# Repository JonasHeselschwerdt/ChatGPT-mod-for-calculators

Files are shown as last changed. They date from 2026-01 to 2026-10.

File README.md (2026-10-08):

# About this project

This repository features a hardware design and code for an ESP32S3 Wroom. With the provided ressources it is possible, to turn any ordinary, non-programmable school calculator into a powerful and programmable device, that connects to the internet via Wifi.
One possible usecase for such a device is the communication with LLM's like ChatGPT, which is implemented in the code.
There are two versions of hardware available. The second, newer version allows for an installation in any calculator with small changes (to the UI-Board and some 3D-prints). The first version is designed specifically to be compatible with the Casio FX87 or FX991.

This is an independent modification, I am not affiliated with Casio Computer Co.,Ltd. or Casio Europe GmbH in any way.

## Documentation of V2

Linked Image (https://youtu.be/zLtktpHgP-4)

## Documentation of V1

Linked Image (https://youtu.be/Xx7Nprghpbg)

## Contact:

If you find bugs in the firmware or you need help setting the device up you can contact me on Youtube, Instagram or here on Github.
Of course I am open to suggestions and collaborations!

Youtube: @ElectrJonics

Instagram: @electrjonics

© 2026 Jonas Heselschwerdt

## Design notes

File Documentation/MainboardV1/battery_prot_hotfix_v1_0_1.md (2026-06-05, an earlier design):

# Hotfix documentation:

I just found out that there is a small flaw in the hardware design of the device.
The battery I recommend for the device (JBL Clip 2 replacement battery) has a battery protection already implemented (see picture below). This can lead to the following problem: When the battery cell voltage drops below a certain treshold of 2.5V the internal battery protection disconnects the output terminal with a mosfet. The battery protection on the PCB misinterprets this as a deeply depleted battery and therefore refuses to charge the battery. In this situation the 2 battery protections deadlock each other. 

To fix this, make the following changes to the PCB:

1) Disconnect JP1
2) Connect the positive battery terminal (red) to Pin 1 of JP1
3) Connect the negative battery terminal (black) directly to GND on one of the pads

With these changes the battery protection on the PCB gets bypassed, as it is not necessary and can cause the problem mentioned above.

Before you attempt this workaround make sure that your battery has a battery protection integrated (experimental or through a datasheet)! Do not operate a battery without any battery protection!

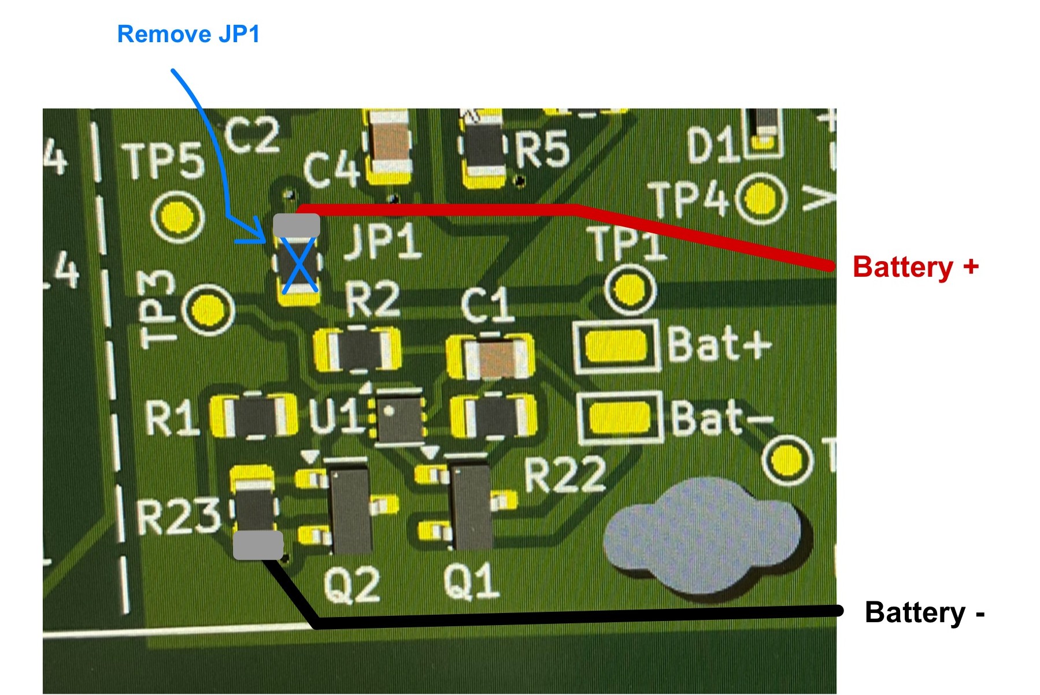
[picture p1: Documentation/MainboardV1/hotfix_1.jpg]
Workaround overview


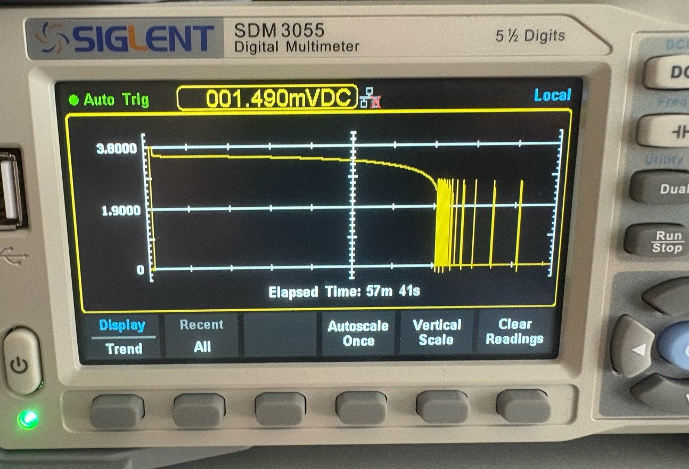
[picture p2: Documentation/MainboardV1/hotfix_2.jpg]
Internal UVP validated


The UVP integrated into the battery shuts off at ~2.5V. Test performed with discharge current of 600mA.
The cell voltage recovers when the load is disconnected, when the load gets reconnected
the cell voltage drops down again, this is why the output voltage 'oscillates' slowly at first. This
eventually stops as the cell voltage goes down further.

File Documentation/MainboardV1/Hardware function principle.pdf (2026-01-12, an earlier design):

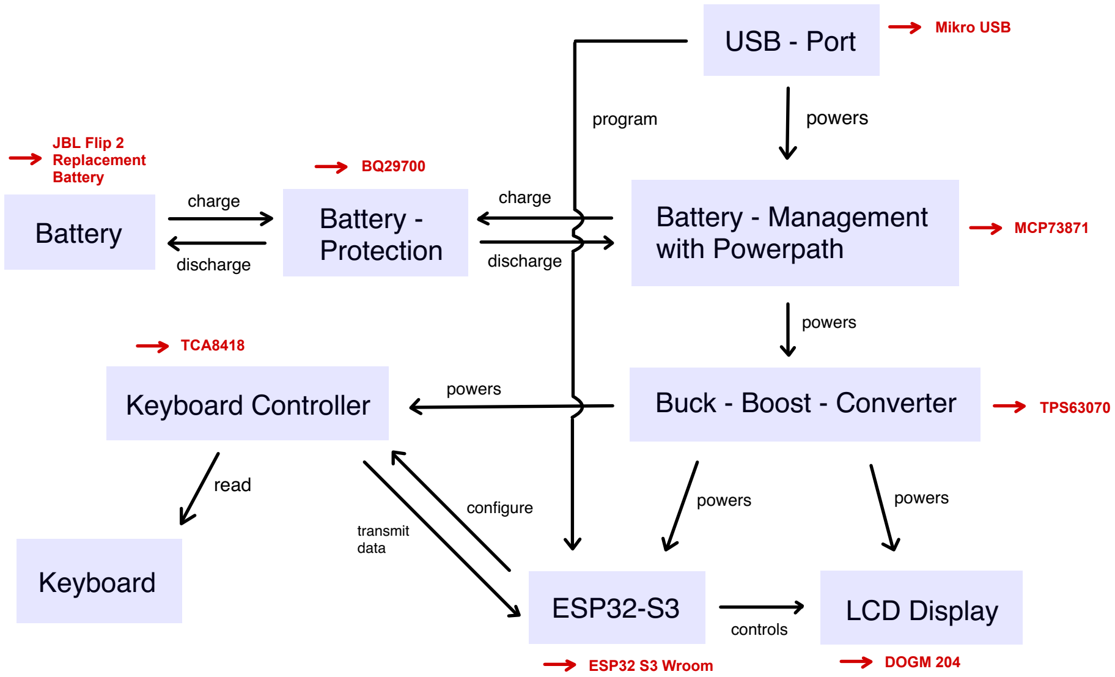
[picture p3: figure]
Battery; USB - Port; Battery - Management with Powerpath; Battery - Protection; Buck - Boost - Converter; ESP32-S3; LCD Display; Keyboard Controller; Keyboard; powers; program; charge; discharge; configure; transmit data; read; controls; Mikro USB; MCP73871; TPS63070; JBL Flip 2 Replacement; TCA8418; ESP32 S3 Wroom; DOGM 204

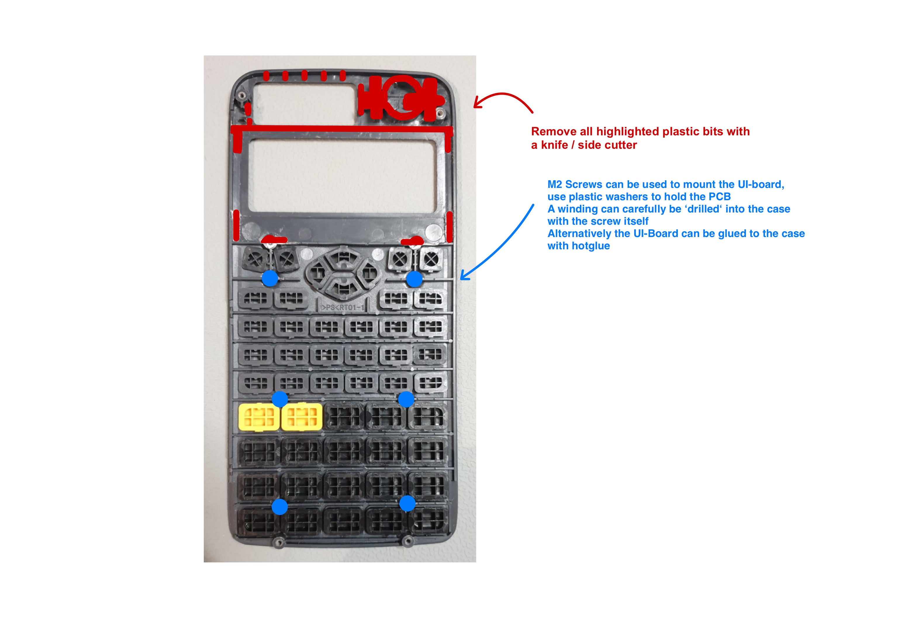
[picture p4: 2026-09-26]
Documentation/MainboardV2_0_3/Frontcasemodifications.JPG

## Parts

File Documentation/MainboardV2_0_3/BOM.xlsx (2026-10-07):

Reference (Mainboard) | Qty | Value | Footprint | Link
C28 | 1 | 10nF 16V 20% X5R | 0603 MLCC
C1,C2,C6,C14,C15,C25,C26,C30,C33,C29 | 10 | 100nF 16V 10% X7R | 0603 MLCC
C3,C7,C8,C9,C10,C24,C27 | 7 | 10µF 16V 20% X5R | 0603 MLCC
C4,C5 | 2 | 4.7µF 16V 10% X5R | 0603 MLCC
C11,C12,C13,C16,C17,C19,C20,C21,C23 | 9 | 22µF 10V 20% X5R | 0603 MLCC
C18 | 1 | 1nF 16V 10% X5R | 0603 MLCC
C22 | 1 | 1µF 25V 20% X5R | 0603 MLCC
C32 | 1 | 22pF 16V 5% COG | 0603 MLCC
D2 | 1 | Yellow | LED 1206
J1 | 1 | Molex Picoblade 3P | Molex PicoBlade 53261-0371 1x03-1MP P1.25mm Horizontal | https://www.reichelt.de/de/de/shop/produkt/molex_stiftleiste_smd_-_picoblade_-_1x3-polig_-_stecker-186227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
J2 | 1 | Molex Picoblade 2P | Molex PicoBlade 53261-0271 1x02 1MP P1.25mm Horizontal | https://www.reichelt.de/de/de/shop/produkt/molex_stiftleiste_smd_-_picoblade_-_1x2-polig_-_stecker-186225
J3 | 1 | Molex Picoblade 6P | Molex PicoBlade 53261-0671 1x06 1MP P1.25mm Horizontal | https://www.reichelt.de/de/de/shop/produkt/molex_stiftleiste_smd_-_picoblade_-_1x6-polig_-_stecker-186229
J4 | 1 | OV5640 Module 68° | 24 Pin FPC Connector Top Contact | https://www.digikey.de/de/products/detail/w%C3%BCrth-elektronik/687124183622/7087317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
J5 | 1 | FPC 24P P0.5 | 24 Pin FPC Connector Top Contact | https://www.digikey.de/de/products/detail/w%C3%BCrth-elektronik/687124183622/7087317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
J6 | 1 | Solderpads
L1 | 1 | 1.5µH SPM5030VT-1R5M-D |  | https://www.digikey.de/de/products/detail/tdk/spm5030vt-1r5m-d/13147343
Q1,Q2 | 2 | SI2300DS-T1GE3 | SOT23-3
Q3,Q4 | 2 | FDV304P | SOT23-3
R1 | 1 | 330R | 0603 Resistor
R2,R3 | 2 | 4.7M | 0603 Resistor
R4,R38 | 2 | 2.2k | 0603 Resistor
R5,R6 | 2 | 5.1k | 0603 Resistor
R7 | 1 | 0R (or solder bridge) | 0603 Resistor
R9 | 1 | 2k (1%) | 0603 Resistor
R10 | 1 | 20k (1%) | 0603 Resistor
R11,R12,R13,R14,R15,R19,R21,R25,R26,R31,R32,R34,R35,R36,R37 | 15 | 10k | 0603 Resistor
R16 | 1 | 470k (1%) | 0603 Resistor
R17 | 1 | 150k (1%) | 0603 Resistor
R18,R24,R40 | 3 | 100k (1%) | 0603 Resistor
R8,R20 | 2 | DNP | 0603 Resistor
R22,R23 | 2 | 22R | 0603 Resistor
R27,R28,R29,R30 | 4 | 4.7k | 0603 Resistor
R33 | 1 | 150R | 0603 Resistor
R41 | 1 | 47k | 0603 Resistor
R39 | 1 | 68R | 0603 Resistor
SW1 | 1 | DIP DHA-02TQR |  | https://www.mouser.de/de/ProductDetail/Diptronics/DHA-02TQR?qs=MLItCLRbWswl9F3kudM7Kw%3D%3D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
U1 | 1 | BQ29700 | WSON-6 1.5x1.5mm P0.5mm | https://www.digikey.de/de/products/detail/texas-instruments/bq29700dser/5973173
U2 | 1 | MCP73871-2CC | QFN-20-1EP 4x4mm P0.5mm EP2.5x2.5mm ThermalVias | https://www.digikey.de/de/products/detail/microchip-technology/mcp73871-2cci-ml/1680971
U3 | 1 | USBLC6-4SC6 | SOT-23-6 | https://www.digikey.de/de/products/detail/stmicroelectronics/USBLC6-4SC6/725216
U4 | 1 | MAX17048G+T10 | TDFN-8-1EP 2x2mm P0.5mm P0.8x1.2mm | https://www.digikey.de/de/products/detail/analog-devices-inc-maxim-integrated/max17048g-t10/3758921
U5 | 1 | TPS63070 | VQFN-15 Power 2.5x3 P0.5 | https://www.digikey.de/de/products/detail/texas-instruments/TPS63070RNMR/6175216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
U6 | 1 | TPS22918 | SOT-23-6 | https://www.digikey.de/de/products/detail/texas-instruments/TPS22918TDBVRQ1/6164978
U7 | 1 | TLV74328PDBV (TLV755… parts are compatible) | SOT-23-5 | https://www.digikey.de/de/products/detail/texas-instruments/TLV74328PDBVR/7593925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
U8 | 1 | TLV74315PDBV (TLV755… parts are compatible) | SOT-23-5 | https://www.digikey.de/de/products/detail/texas-instruments/TLV75515PDBVR/9356527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
U9 | 1 | TCA8418 | WQFN-24-1EP 4x4mm P0.5mm EP2.45x2.45mm ThermalVias | https://www.digikey.de/de/products/detail/texas-instruments/tca8418rtwr/2172843
U10 | 1 | ESP32-S3-N16R8 | ESP32-S3 Wroom | https://www.digikey.de/de/products/detail/espressif-systems/ESP32-S3-WROOM-1-N16R8/16162642
Y1 | 1 | Abracon ASE-24.000MHZ-L-C-T | XO32-4Pin 3.2x2.5mm | https://www.digikey.de/de/products/detail/abracon-llc/ASE-24-000MHZ-L-C-T/1236883
Reference (UI-Board) | Qty | Value | Footprint | Link
C12, C14 | 2 | 100nF 16 10% X7R | 0603 MLCC
C1, C2, C3, C4, C5, C6, C7, C13 | 8 | 1µF 25V 20% X5R | 0603 MLCC
C9, C10 | 2 | 220nF 16V 10% X7R | 0603 MLCC
C8, C11 | 2 | 4.7µF 16V 10% X5R | 0603 MLCC
R1 | 1 | 220R (1%) | 0603 Resistor
R2 | 1 | 47R (1%) | 0603 Resistor
U1 | 1 | DEP128064D-W |  | https://www.tme.eu/de/details/dep128064d-w/graphische-oled-displays/display-elektronik/dep-128064d-w/
U2 | 1 | DOGM204N-A |  | https://www.mouser.de/de/ProductDetail/Display-Visions/EA-DOGM204N-A?qs=ZP3UR5XsUoe%252B6vE6qC3WmQ%3D%3D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
Additionally required: | Qty | Link
Screws M2x8 | 4
Screws M2x4 | 3
Threaded Insert M2x3x3.2mm (Height x Shell Diameter) | 2
24 Pin FPC Cable 100mm One sided P=0.5mm | 1 | amazon.de/dp/B09TR71N42?ref=ppx_yo2ov_dt_b_fed_asin_title
USB-C to 6 Wire Connector | 1 | https://www.amazon.de/dp/B0CZHLRJRD?ref_=ppx_hzsearch_conn_dt_b_fed_asin_title_2&th=1
Pre Crimped JST PB Wire | 1 Set | https://www.amazon.de/dp/B0D33JCWM2?ref_=ppx_hzsearch_conn_dt_b_fed_asin_title_1
M2.5 Screws | 1 Set | https://www.amazon.de/dp/B0CY1YZZC8?ref_=ppx_hzsearch_conn_dt_b_fed_asin_title_2&th=1
M2.5 Nuts | 1 Set | https://www.amazon.de/dp/B0CY1YZZC8?ref_=ppx_hzsearch_conn_dt_b_fed_asin_title_2&th=1

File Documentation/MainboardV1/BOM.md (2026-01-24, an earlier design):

# Bill of materials

**Important: All links lead to exactly the parts I bought**  
**Some links lead to german shops that only ship withing europe**

**Check the manufacturer part code if you are ordering from other shops**  
**because there are different versions available!**

## Resistors

|Part|Value|
|--|--|
|R1|2.2kΩ|
|R2|330Ω|
|R3|20kΩ|
|R4, R24|2kΩ|
|R5|68kΩ|
|R6|200kΩ|
|R7 ,R12 ,R15 ,R17 ,R18 ,R19 |10kΩ|
|R8|470kΩ|
|R9|150kΩ|
|R10, R11|100kΩ|
|R13, R14|33Ω|
|R16|47kΩ|
|R20, R21|4.7kΩ|
|R22, R23|4.7MΩ|

**All resistors are 0805 / 5% / 0.125W**

## Capacitors

|Part|Value|
|--|--|
|C1, C7|100nF, 0805 MLCC, 16V|
|C2, C4|4.7µF, 0805 MLCC, 16V|
|C3, C5, C6|10µF, 0805 MLCC, 16V|
|C8, C9|10µF, 0603 MLCC, 16V|
|C10, C11, C12|22µF, 0805 MLCC, 16V|
|C13 - C19, C21, C22|1µF, 0805 MLCC, 16V|
|C20, C23|100nF, 0603 MLCC, 16V|

**Use X5R or X7R type Capacitors**  
**10% tolerance Capacitors are recommended**  
**Voltage ratings can be changed, should be >= 6.3V**  

## Semiconductor parts

|Part|Value|Link|
|--|--|--|
|D1|PJSD05TS-AU, 5V TVS Diode, SOD-523| https://www.digikey.de/de/products/detail/panjit-international-inc/PJSD05TS-AU-R1-000A1/14660395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 |
|D2|PJSD03TS-AU, 3.3V TVS Diode, SOD-523| https://www.digikey.de/de/products/detail/panjit-international-inc/PJSD03TS-AU-R1-000A1/15796332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 |
|D3|1N4148 SOD-323| https://www.reichelt.de/de/de/shop/produkt/kleinsignal-schalt-diode_100_v_300_ma_sod-123-219381 |
|D4|1206 LED, Yellow| / |
|Q1,Q2|SI2300DS-T1-GE3, N-ch. FET, SOT-23| https://www.digikey.de/de/products/detail/vishay-siliconix/SI2300DS-T1-GE3/2441582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 |
|Q3|2N7002 N-Ch. FET, SOT-23| https://www.reichelt.de/de/de/shop/produkt/mosfet_n-ch_60v_0_38a_0_42w_1_6r_sot-23-379109 |

## IC's and MCU's

|Part|Value|Link|
|--|--|--|
|U1|BQ29700 (Texas Instruments)| https://www.digikey.de/de/products/detail/texas-instruments/BQ29700DSER/5973173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 |
|U2|MCP73871-2CC (Microchip)| https://www.digikey.de/de/products/detail/microchip-technology/MCP73871-2CCI-ML/1680971 |
|U3|TPS630702 (Texas Instruments)| https://www.digikey.de/de/products/detail/texas-instruments/TPS630702RNMR/10434765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 |
|U4|ESP32-S3 Wroom N16R8 (Espressif)| https://www.conrad.de/de/p/espressif-esp32-s3-wroom-1-n16r8-wifi-erweiterungsmodul-1-st-3027854.html |
|U5|DOGM204N-A (Display Vision)| https://www.digikey.de/de/products/detail/display-visions/EA-DOGM204N-A/4896724 |
|U6|TCA8418 (Texas Instruments)| https://www.digikey.de/de/products/detail/texas-instruments/TCA8418RTWR/2172843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 |

## Miscellaneous

|Part|Value|Link|
|--|--|--|
|BT1|JBL Clip 2 replacement battery, 3.7V lithium-polymer, 800mAh|https://www.reichelt.de/de/de/shop/produkt/ersatzakku_jbl_clip_2_li-po_800_mah-312907|
|F1|600 mA 1206 PTC Fuse (not used!) -> 0Ω 1206 Resistor or Solder Bridge| / |
|J3|USB Jack | https://www.amazon.de/dp/B0B18J82G3?ref=ppx_yo2ov_dt_b_fed_asin_title (Set) |
|L1|1,5µH shielded SMD power inductor|https://www.digikey.de/de/products/detail/bourns-inc/SRP6530A-1R5M/14654440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 |
|JP1, JP2, JP3|0805 0Ω Resistor| / |
|Screws PCB -> Front case|M1.4x4 screws (x4)|https://www.amazon.de/dp/B08GLFG1WZ?ref_=ppx_hzsearch_conn_dt_b_fed_asin_title_2 (Set)|
|Screws Back case -> Front case|M2x8 screws (x4)|https://www.amazon.de/dp/B08GLFG1WZ?ref_=ppx_hzsearch_conn_dt_b_fed_asin_title_2 (Set)|

**J3 needs to be modified to fit on the PCB**

|Recommended 3d prints| 
|--|
|4x PCB_case_connector_washer.3mf|
|1x Plastic_bracket.3mf (connect with double sided tape to PCB)|
|1x Solar_panel_holder.3mf (connect with double sided tape to PCB)|

## Programming tool

|Part|Value|Link|
|--|--|--|
|Plastic housing|Dupont connector housing 2x2|https://www.amazon.de/dp/B09NBT7D9P?ref_=ppx_hzsearch_conn_dt_b_fed_asin_title_3 (Set)|
|Pogo Pins|1.5mm Pogo Pins|https://www.amazon.de/dp/B07SHCJT6L?ref_=ppx_hzsearch_conn_dt_b_fed_asin_title_2|
|Shrinking tube|Shrinking tube, 9mm diameter|https://www.amazon.de/dp/B0CDC1DBPF?ref_=ppx_hzsearch_conn_dt_b_fed_asin_title_1 (Set)|
|Super glue|UHU superglue (liquid)|/|

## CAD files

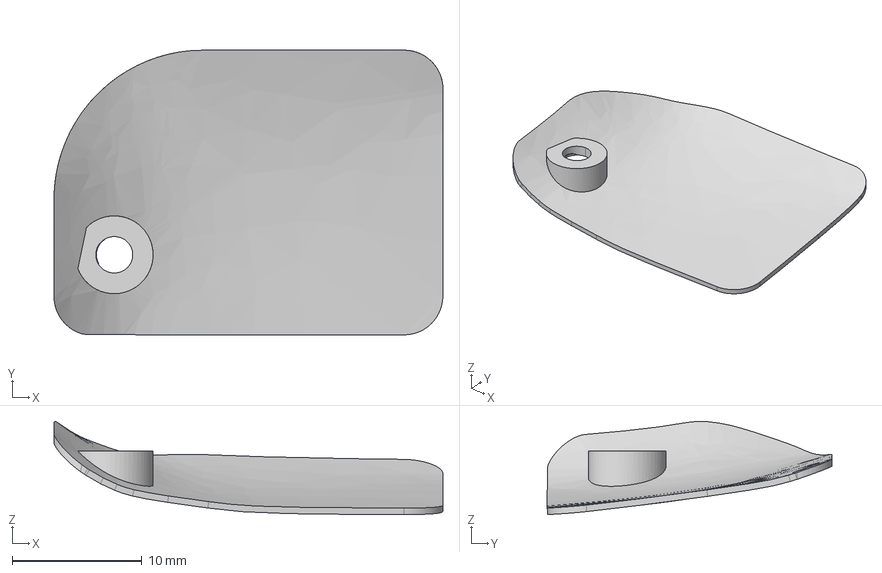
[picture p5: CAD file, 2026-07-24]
3D Prints/For_MainboardV2/BatteryTrayFX991_FX87.step
30.0 x 22.0 x 7.18 mm

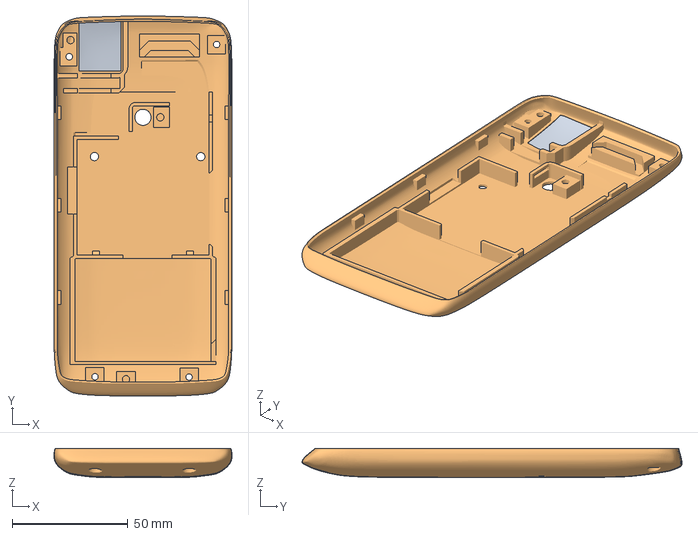
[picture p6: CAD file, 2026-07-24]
3D Prints/For_MainboardV2/BackcaseFX991_FX87.3mf
76.9 x 164.4 x 12.6 mm
Abdeckung
Gehaeuse

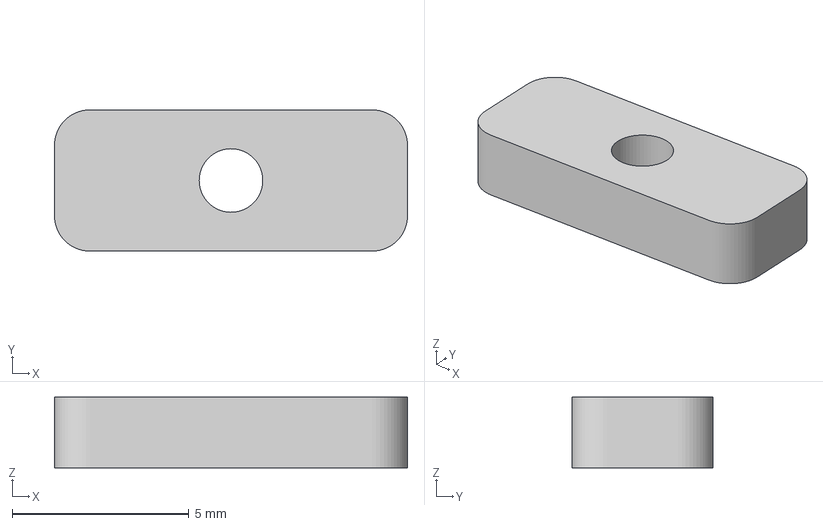
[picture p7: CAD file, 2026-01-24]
3D Prints/For_MainboardV2/Washer_Thingy_for_UI_Board.3mf
10.0 x 4.00 x 2.00 mm

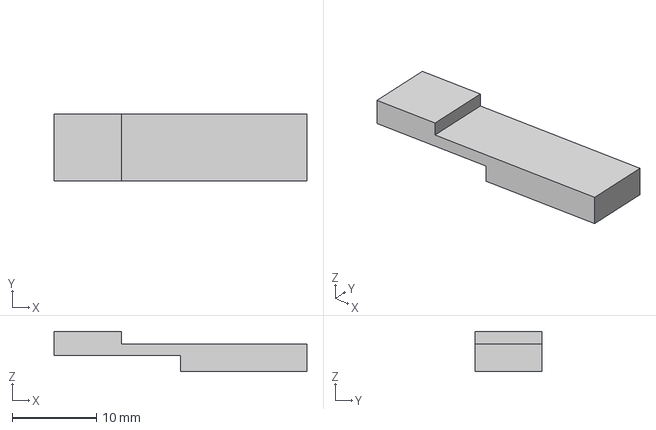
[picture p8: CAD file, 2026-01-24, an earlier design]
3D Prints/For_MainboardV1/Solar_panel_holder.3mf
30.0 x 8.00 x 4.80 mm

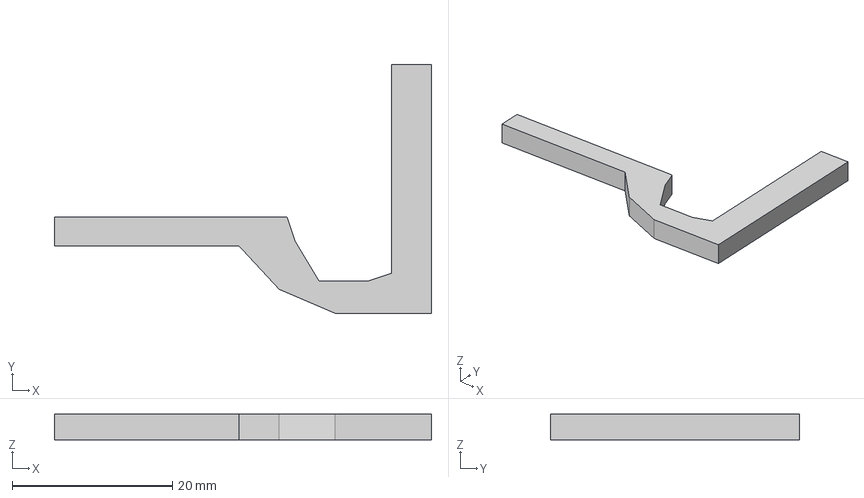
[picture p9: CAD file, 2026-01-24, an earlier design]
3D Prints/For_MainboardV1/Plastic_bracket.3mf
47.0 x 31.0 x 3.20 mm

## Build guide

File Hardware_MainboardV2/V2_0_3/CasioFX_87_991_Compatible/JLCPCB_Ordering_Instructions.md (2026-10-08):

# How to order the boards (from JLCPCB)

If you want to get your own copy of the mainboard and UI-Board I recommend JLCPCB
as PCB manufacturer.

To get the boards upload the Gerber files (one by one) as .zip on https://jlcpcb.com/ -> Get instant quote

## After that you can set some settings:

- PCB Qty: Set how many boards you need
- PCB thickness: Set to 0.8mm (for both boards)
- Surface finish: ENIG heavily recommended for UI-board, mainboard can be HASL or ENIG
- For mainboard activate either 'PCB assembly' (let JLCPCB handle assembly) or 'Solder stencil' (assemble board yourself)
- Leave all other settings in their default state. When using PCB assembly services, extra files are necessary (not on Github yet)

## Mainboard solder stencil

- Stencil side: Top only
- Polishing process: Electropolishing
- Leave all other settings in their default state

## Transparency note:

JLCPCB is the sponsor of some of my videos

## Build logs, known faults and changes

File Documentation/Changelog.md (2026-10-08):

# Changelog - Casio FX Series Hardware Mod User Interface

## Version 1.0.0 (non-public)

First version of the firmware.

Abilities:

- Save one WIFI SSID + Password (typed into source code)
- Save on API- Key (typed into source code)
- Prompt processing and displaying the answer from OpenAI API

## Version 1.0.1

Improvements:

- Added Menu Mode
- Save up to 8 WIFI credentials directly via the UI
- Save API Key directly via the UI

## Version 1.1.0

Improvements:

- Device can load HTML files from local http servers and saves them into flash memory (non volatile) via littleFS
- Added 'stealth mode' upon start (device works like regular calculator when starting)
- Added Auto off feature (user can change time limit)
- Added factory reset ability
- Added USB HID mode (device can act as keyboard)
- Added ability to change GPT models
- Increased maximal ChatGPT answer length from 480 ASCII chars to 4800

Note: A text transfer tool to upload texts to the device was added

## Version 2.0.0

- Changed maindisplay driver functions
- Added U8G2 based sidedisplay driver module
- Added batterymanagement module
- Changed keypad driver functions
- Added ESP-camera based camera module
- Switched to OpenAI responses API (supports newer models, supports conversations up to 20 responses long)
- Added abiltiy to render equations (needs external python server)
- Added abiltiy to send JPGs to OpenAI responses API
- Increased WIFI credentials storage to 16 WIFIs
- Added new UI-mode: Textinputmode
- Changed Menumode, Scribblemode, Chatviewmode and Calculatormode (previously called 'stealth mode')
- Removed Fileviewmode
- Removed USB Keypadmode
- Changed unlock method from secret key-combination to (user-configurable) UI-unlock code
- Added a device name variable (user-configurable)
- Added a debug mode that enables experimental settings and debug messages

# Changelog - HTML local network hosting tool (text transfer tool)

## Version 1.0.0

Initial version:

- Up to 9 different text sections (each up to 80.000 ASCII chars)
- Automatic formatting (removing non-ASCII signs, removing formatting signs (\\n, \\t, etc.))

# Changelog - Hardware

## Version 1.0.0

Initial version:

- 3.7V LiPo Battery integrated
- Battery protection circuit
- Battery management with powerpath
- Buck boost converter (3.3V output)
- USB port on the side of the board
- ESP32S3 wroom module with onboard antenna
- Powerlatch circuit
- Membrane keypad controlled by GPIO expander
- 20x4 text LCD (no backlight)

## Version 1.0.1 (Hotfix)

- Fixed 'deadlock' issue of battery protection (see battery_prot_hotfix_v1_0_1.md)

## Version 2.0.0 (new codebase)

- Split electronics into Mainboard and UI-Board, connected by 24 Pin FPC connector
- Battery and USB-C connector connected via Molex Picoblade Connectors (instead of soldered on)
- Replaced programming pads with a SMD low profile DIP switch
- Made bypassing the on-board battery protection easier (see v.1.0.1)
- Improved ESD-Protection of USB-Connector
- Added fuel gauge IC to monitor battery charge state via I2C
- Added a switch to manually turn of the main 3.3V rail
- Added an interface for a OV5640 camera module including power supply and clock source
- Switched 20x4 text LCD interface to I2C
- Improved power latch circuit
- Rerouted output signals of BMS to TCA8418 inputs
- Added an user extension interface offering up to 10 free GPIOs + I2C
- Added a second graphic display (128x64 OLED screen)
- Reactivated the 4 previously missing buttons
- Added testpoints and solder jumpers for easy modifications/testing
- Improved keypad button footprints
- Added on-board LED for use during debugging (disconnected by default)
- Added support for an external NTC-Thermistor for battery temperature monitoring

## Version 2.0.1

- Repurposed FreeGPIO9 to NTC-Voltage Divider activation Pin (FreeGPIO9 not available anymore)
- Added Ability to monitor the battery cell temperature with the ESP32S3 ADC1 Channel 2 (GPIO 3)
- Added a 100nF Capacitor from 3V3_Main_disable to make it less susceptible to noise
- Added copper pours at input pins of TPS63070 and MCP73871 to decrease thermal resistance to the PCB
- Disabled VPCC function of MCP73871 as it led to problems when the device is only powered through USB
- More infos: fixes_v2_0_1_documentation.md
- Replaced FPC connector link in BOM

## Version 2.0.2

- Software compatible to V2.0.1
- Removed JP6:9, no longer necessary
- Routing changes to Mainboard and UI-Board
- Improved User extension interface to be easier to use
- Added some empty space near user extension interface for further extensions
- Added Kicad template project for user extension board

## Version 2.0.3 (small fixes)

- Corrected Pitch of SW1 on mainboard to 1.27mm
- Corrected Edge-Cuts outline of UI-Board to not collide with front case anymore
- Cleaned up footprint library

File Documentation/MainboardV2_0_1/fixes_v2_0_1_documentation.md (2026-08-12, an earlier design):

# Hardware Version v2.0.1

In this newest version some small changes to the board are made. They allow measuring the temperature
of the battery even when the MCP73871 is not active with an ADC of the ESP32S3. Also the VPCC function of
the MCP73871 gets deactivated as it caused problems when powering the device with just USB and no battery.
The PCB gerber files in the Hardware-Folder (v2_0_1) have these changes implemented, as well as routing improvements
for the power electronics.

## Upgrading Hardware v2.0.0 to v2.0.1

If you already ordered the v2.0.0 board, it can be upgraded:

1) Connect TP29 to TP14 or Pin 1 of J2 with a 100k Resistor
2) Connect TP14 or J2 Pin 1 with a 47k Resistor to GPIO3 (Pin 15) of the ESP32
3) Connect GPIO3 (Pin 15) of the ESP32 to a 10nF capacitor to GND (for example JP2)
4) Connect Pin 1 of SW1 with a 100nF capacitor to GND (for example Pin 3 or 4 of SW1)
5) Replace R7 with a 0 Ohm bridge or a solder bridge
6) Remove R8

For the modifications I recommend some 32AWG or 30AWG wire wrapping wire, Software Version v2.0.0 will require all changes
to the hardware listed above to be made on your hardware.

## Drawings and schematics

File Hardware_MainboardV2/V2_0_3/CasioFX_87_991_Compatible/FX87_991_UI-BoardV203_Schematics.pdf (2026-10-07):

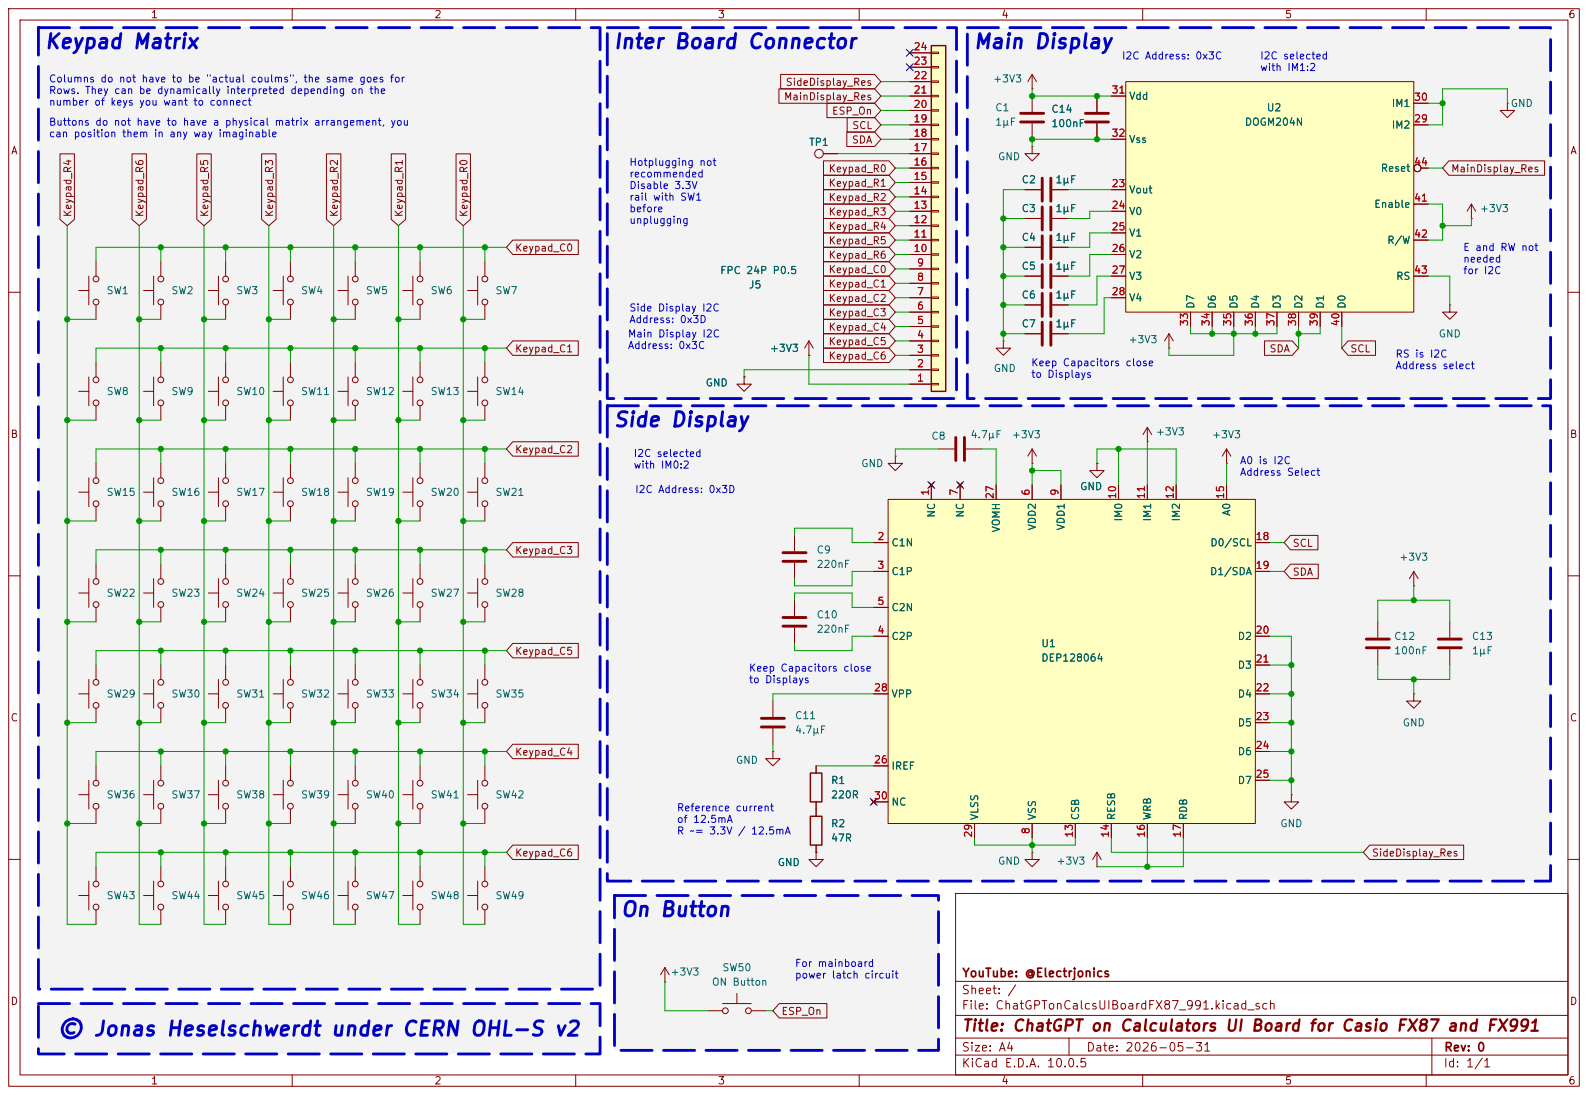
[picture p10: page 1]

Buttons do not have to have a physical matrix arrangement, you can position them in any way imaginable

rail with SW1
before unplugging Side Display I2C

Address: 0x3D
to Displays Main Display I2C Address: 0x3C

Address select Keep Capacitors close

9 IM0 10 IM1 11 IM2 12 CSB 13 RESB 14 A0 15 WRB 16 RDB 17

to Displays Reference current of 12.5mA R ~= 3.3V / 12.5mA

On Button

For mainboard power latch circuit

© Jonas Heselschwerdt under CERN OHL-S v2

Sheet: /
File: ChatGPTonCalcsUIBoardFX87_991.kicad_sch
Title: ChatGPT on Calculators UI Board for Casio FX87 and FX991

Size: A4 | Rev: 0
KiCad E.D.A. 10.0.5 | Id: 1/1

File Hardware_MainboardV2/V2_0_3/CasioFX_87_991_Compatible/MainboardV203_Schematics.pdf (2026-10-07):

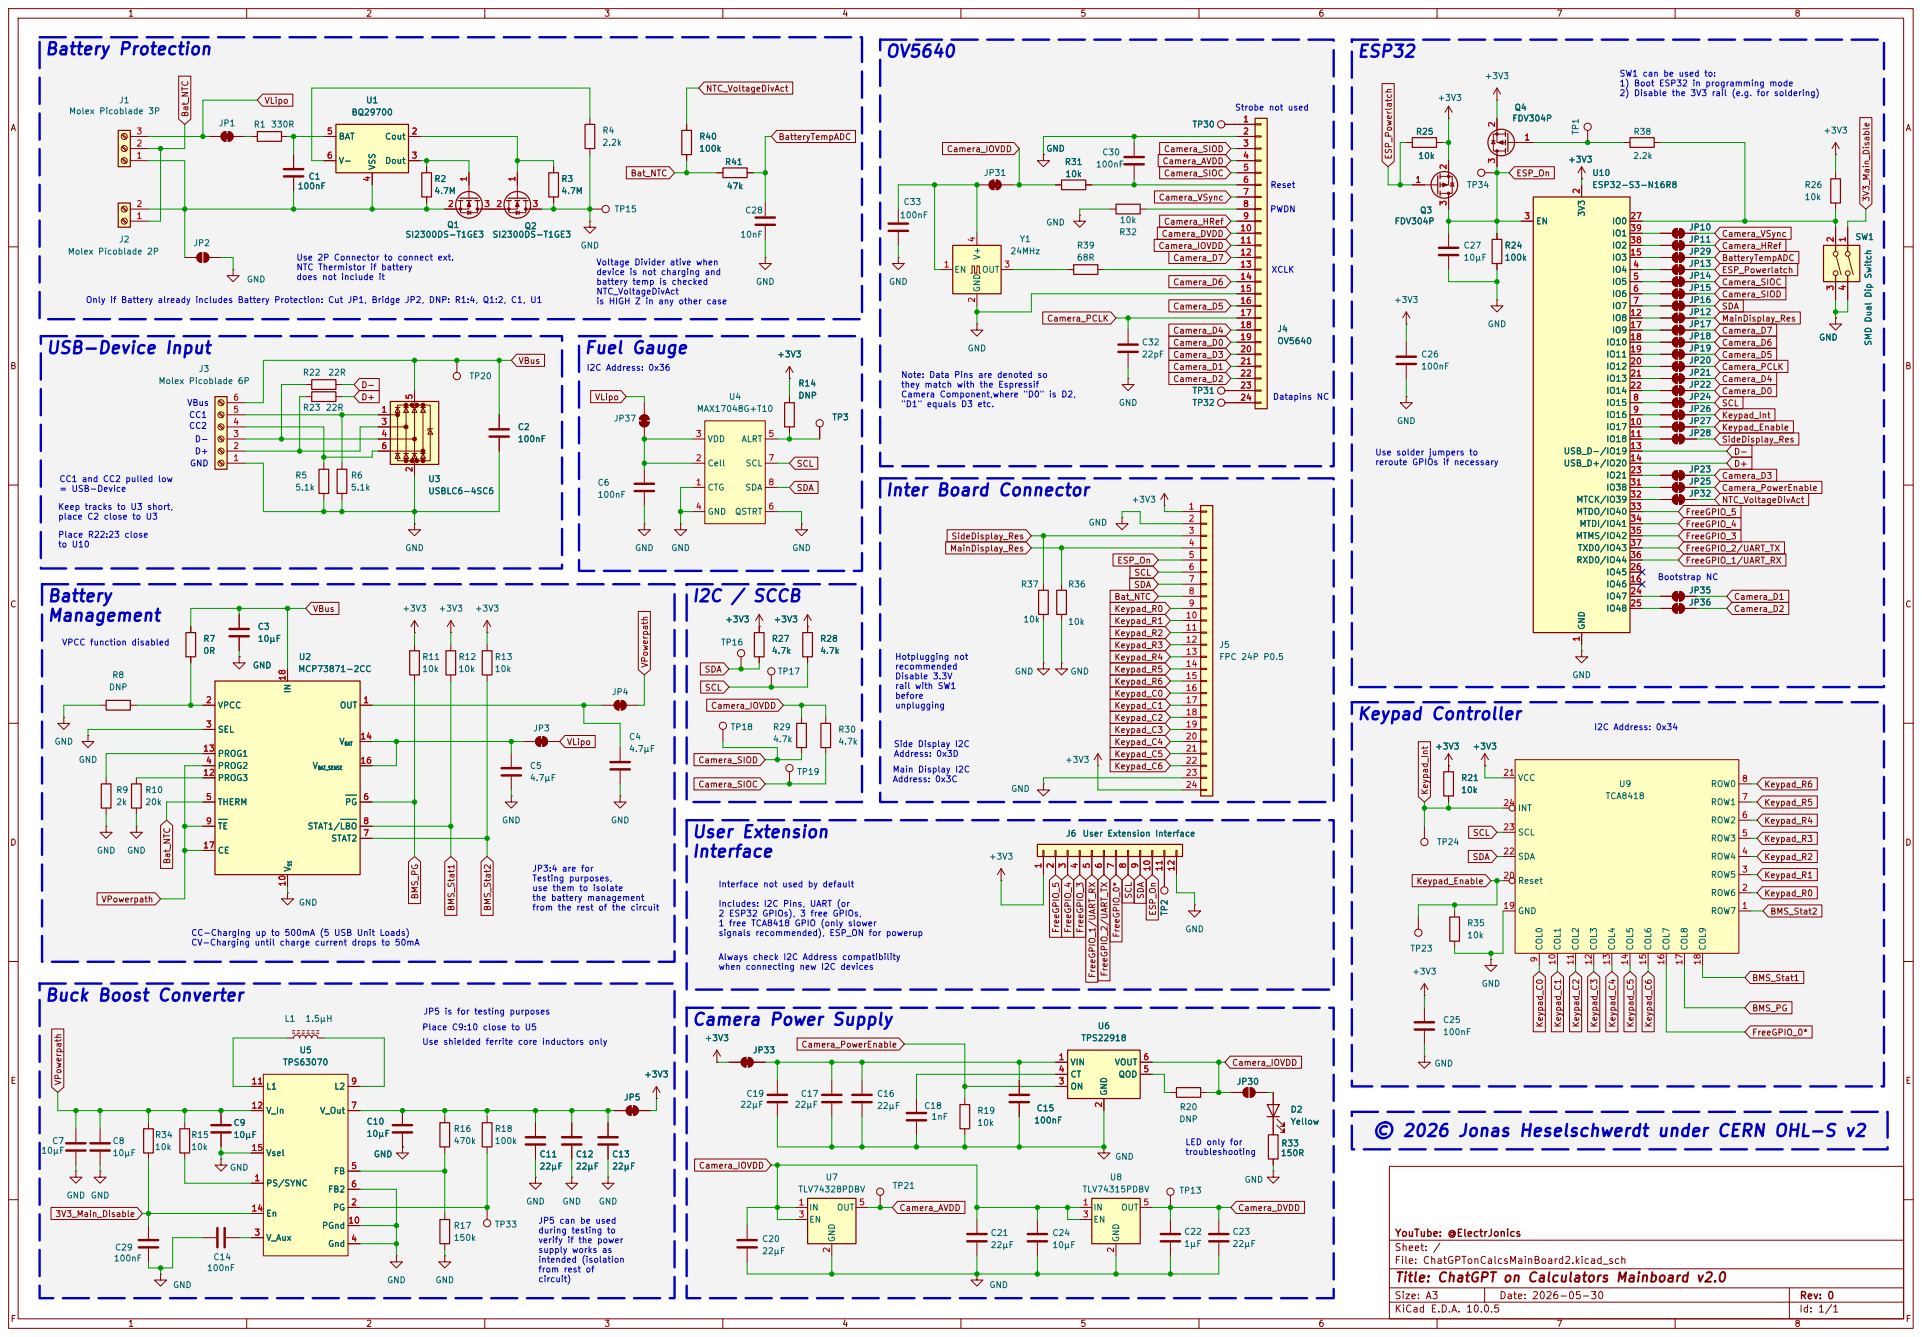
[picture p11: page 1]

Reset Note: Data Pins are denoted so

XCLK Only if Battery already includes Battery Protection: Cut JP1, Bridge JP2, DNP: R1:4, Q1:2, C1, U1

Voltage Divider ative when
device is not charging and
battery temp is checked NTC_VoltageDivAct

is HIGH Z in any other case D+

they match with the Espressif Camera Component,where "D0" is D2,
Datapins NC Main Display I2C Address: 0x3C

Use solder jumpers to
reroute GPIOs if necessary

CC1 and CC2 pulled low = USB-Device

IO38 31 MTCK/IO39 32 MTDO/IO40 33 MTDI/IO41 34 MTMS/IO42 35 RXD0/IO44 36 TXD0/IO43 37

Keep tracks to U3 short, place C2 close to U3 Place R22:23 close

Address: 0x3D Hotplugging not recommended Disable 3.3V

JP3:4 are for
Testing purposes, use them to isolate

Interface not used by default

the battery management
from the rest of the circuit

Includes: I2C Pins, UART (or 2 ESP32 GPIOs), 3 free GPIOs, 1 free TCA8418 GPIO (only slower signals recommended), ESP_ON for powerup

Always check I2C Address compatibility when connecting new I2C devices

JP5 is for testing purposes
Place C9:10 close to U5 Use shielded ferrite core inductors only

© 2026 Jonas Heselschwerdt under CERN OHL-S v2

JP5 can be used during testing to

verify if the power supply works as

intended (isolation
from rest of circuit)

Id: 1/1 Title: ChatGPT on Calculators Mainboard v2.0

Size: A3 | Rev: 0
F Date: 2026-05-30 KiCad E.D.A. 10.0.5

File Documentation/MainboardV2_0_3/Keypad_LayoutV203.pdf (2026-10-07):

·
T

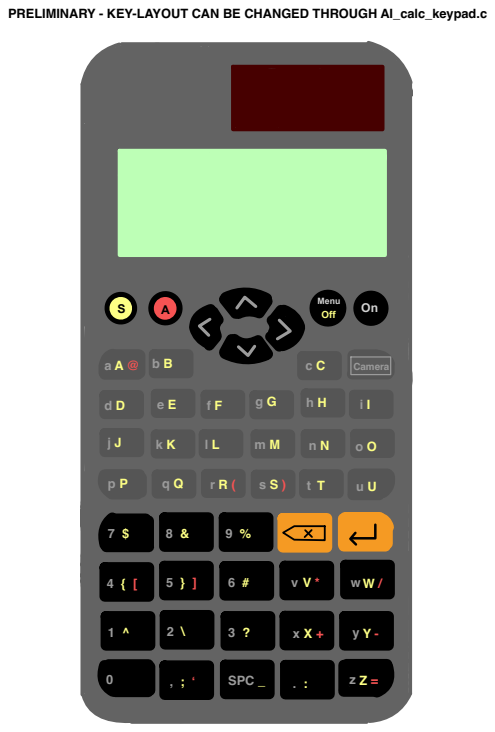
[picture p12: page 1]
Menu; On Off S; SPC _; Camera; PRELIMINARY - KEY-LAYOUT CAN BE CHANGED THROUGH AI_calc_keypad.c I· ·; zur; U⁰⁰ -; oror

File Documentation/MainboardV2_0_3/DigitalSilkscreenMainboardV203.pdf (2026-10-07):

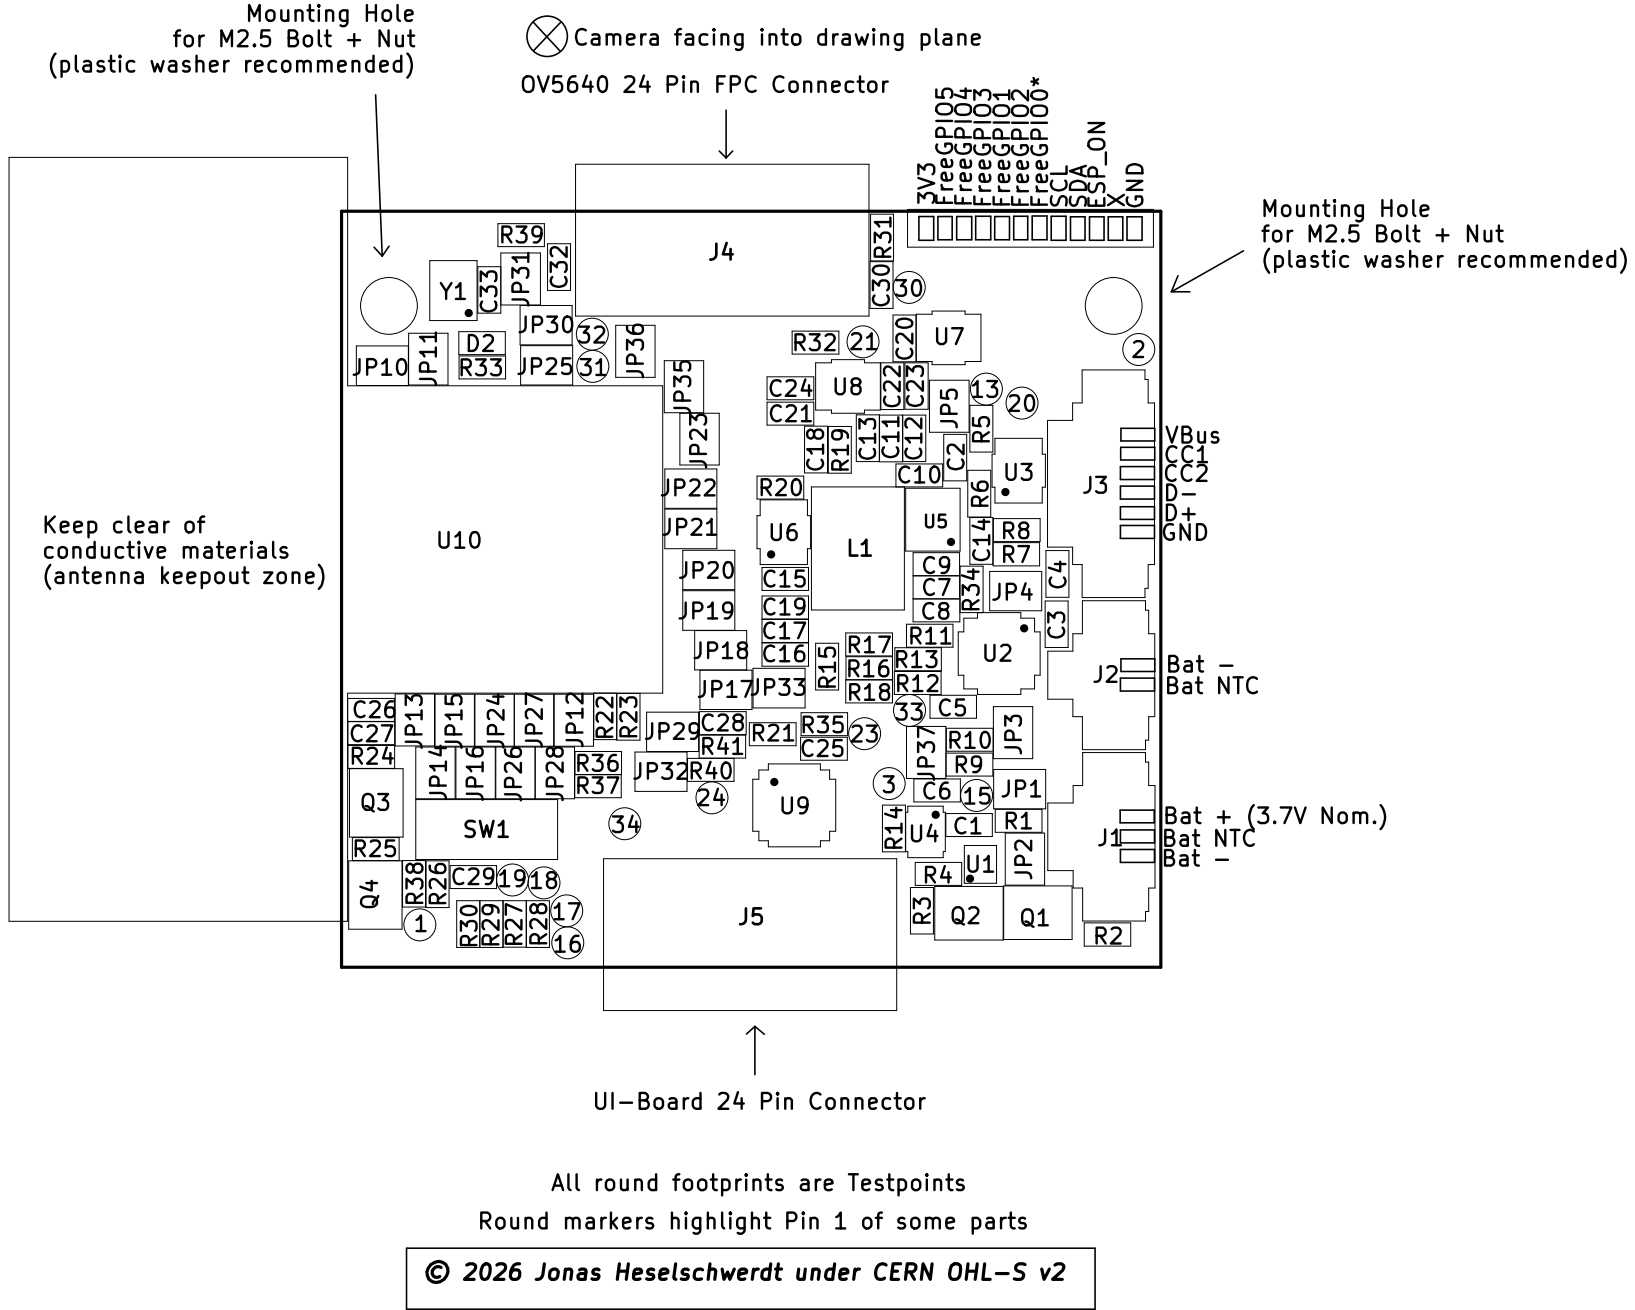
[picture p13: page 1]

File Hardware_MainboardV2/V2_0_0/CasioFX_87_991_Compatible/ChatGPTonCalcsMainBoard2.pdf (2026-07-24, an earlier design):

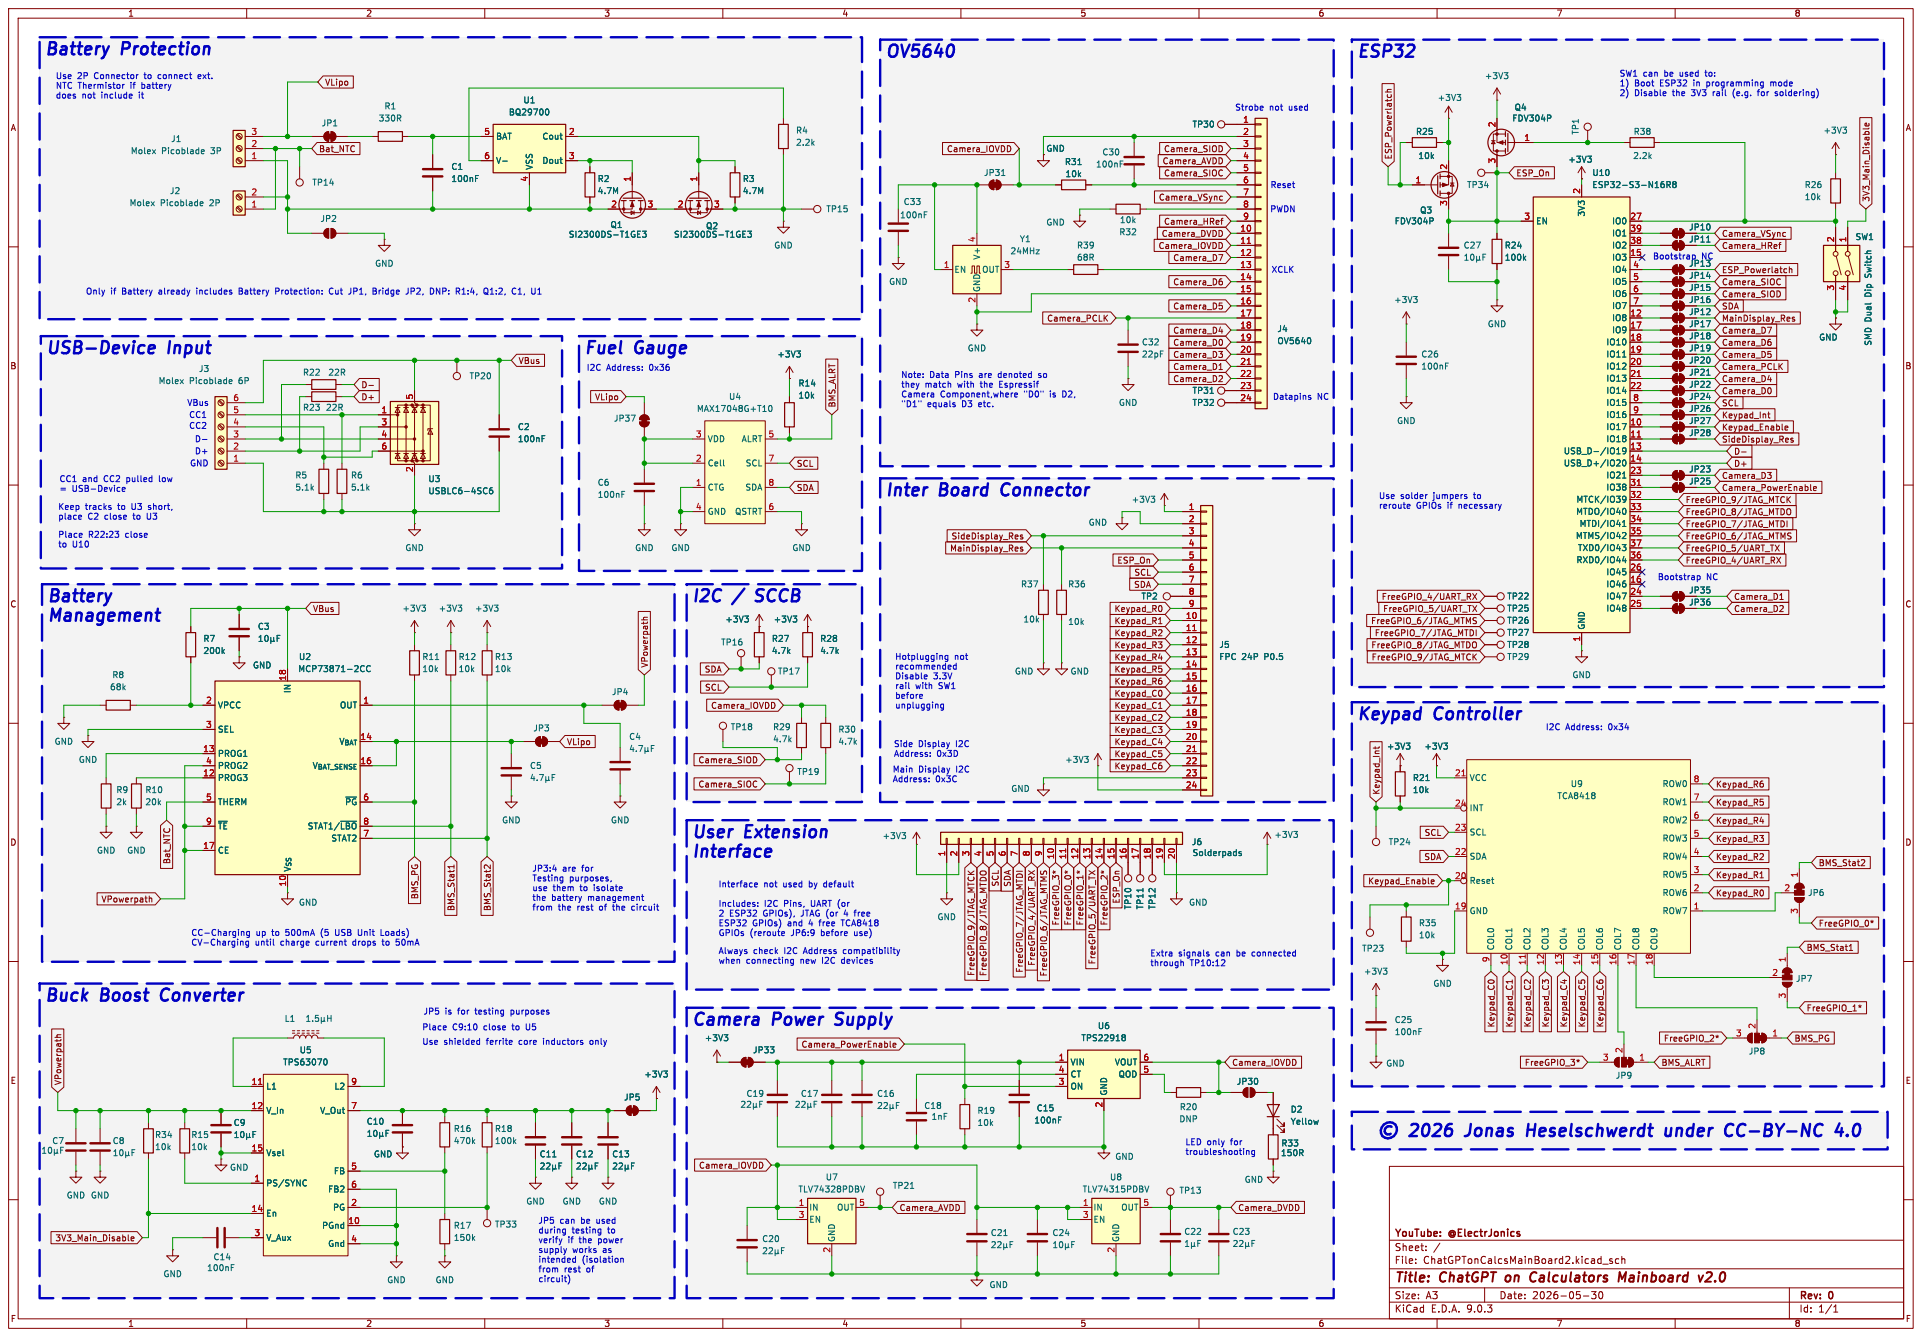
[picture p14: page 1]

2) Disable the 3V3 rail (e.g. for soldering) Reset

I2C Address: 0x36 CC1 and CC2 pulled low

I2C Address: 0x34 Note: Data Pins are denoted so

IO38 31 MTCK/IO39 32 MTDO/IO40 33 MTDI/IO41 34 MTMS/IO42 35 TXD0/IO43 37 RXD0/IO44 36

from the rest of the circuit JP5 is for testing purposes

2 VOUT 6 QOD 5 U6 TPS22918 GND
L1 11 V_In 12 Vsel 15 PS/SYNC 1 En 14 V_Aux 3

L2 9 V_Out 7 FB 5 FB2 6 PG 2 PGnd 10 Gnd 4 C10

JP5 can be used
during testing to
verify if the power supply works as

File: ChatGPTonCalcsMainBoard2.kicad_sch Sheet: / YouTube: @ElectrJonics

from rest of circuit)

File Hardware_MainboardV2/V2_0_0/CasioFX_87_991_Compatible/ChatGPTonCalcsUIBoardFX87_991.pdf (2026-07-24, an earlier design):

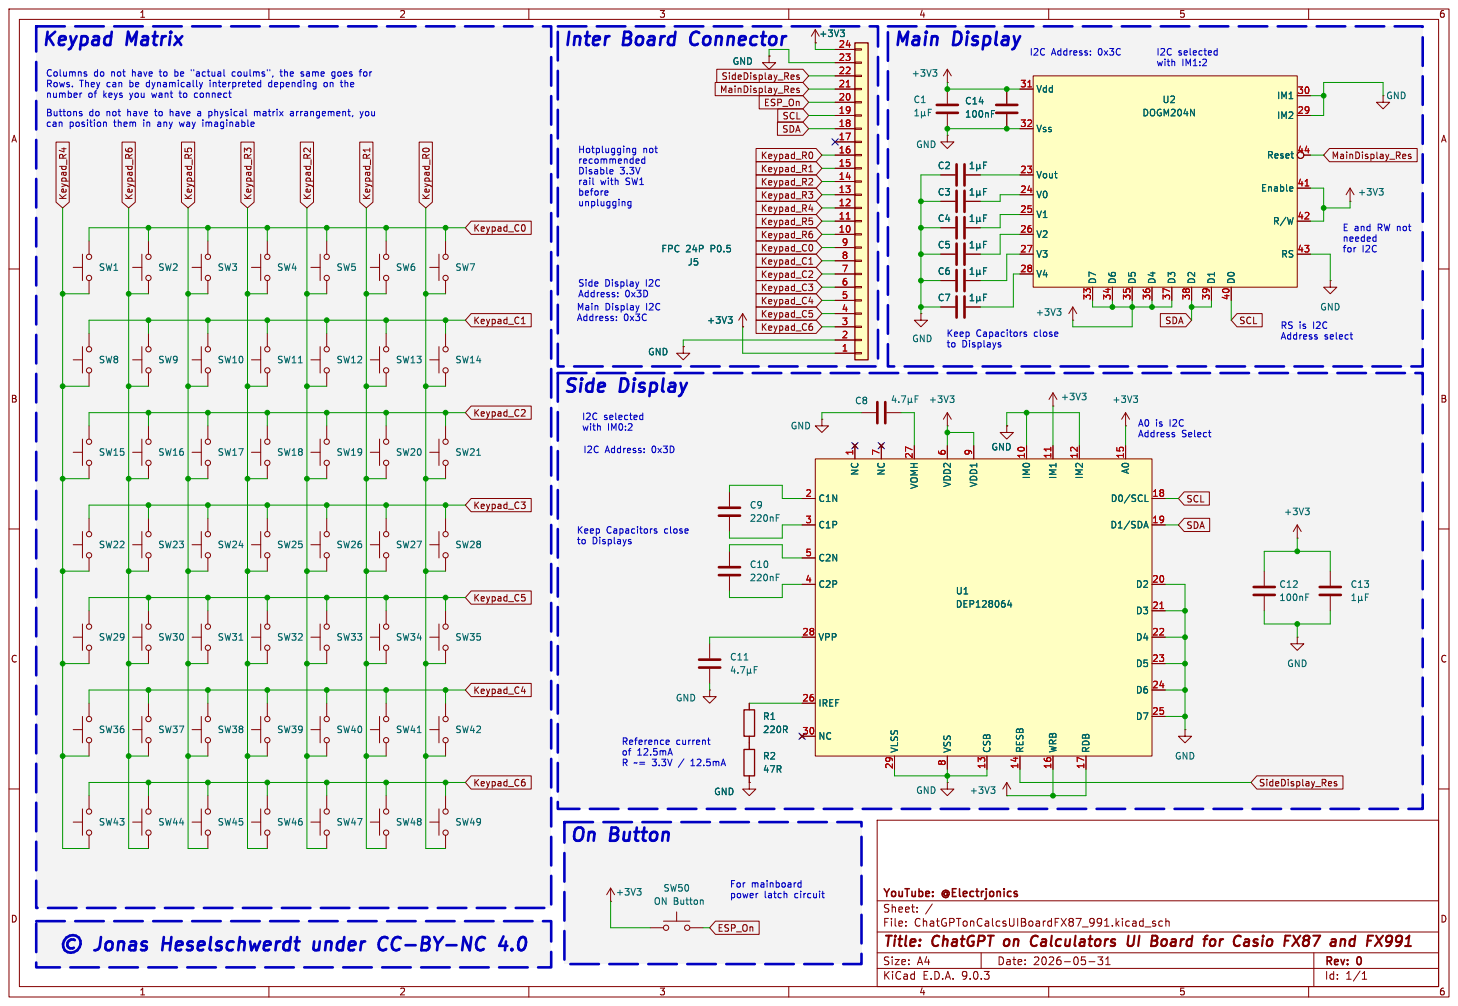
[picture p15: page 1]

I2C selected with IM1:2 Side Display I2C

Address selectE and RW not needed

9 CSB 13 RESB 14 IM0 10 IM1 11 WRB 16 IM2 12 RDB 17 A0 15 D0/SCL 18 D1/SDA 19 D2 20 D3 21 D4 22 D5 23 D6 24 D7 25 U1 DEP128064 SW25 SW26 +3V3 +3V3

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

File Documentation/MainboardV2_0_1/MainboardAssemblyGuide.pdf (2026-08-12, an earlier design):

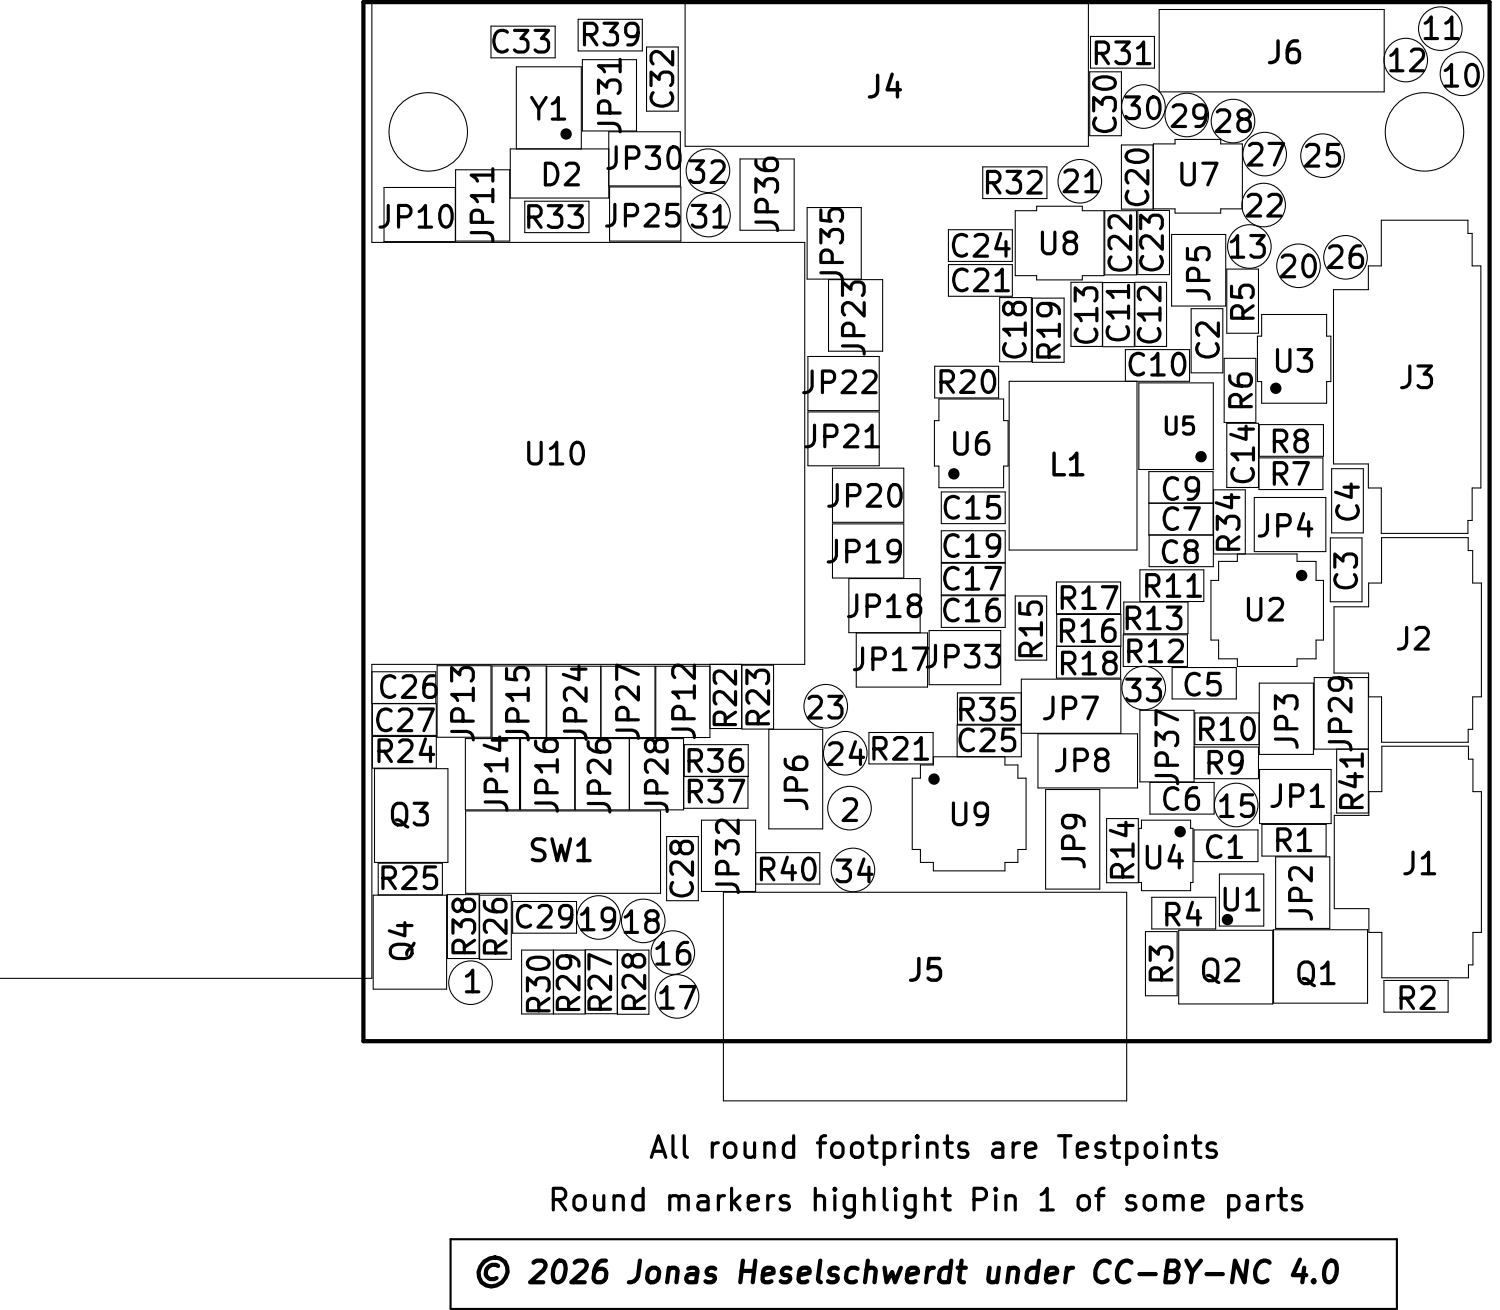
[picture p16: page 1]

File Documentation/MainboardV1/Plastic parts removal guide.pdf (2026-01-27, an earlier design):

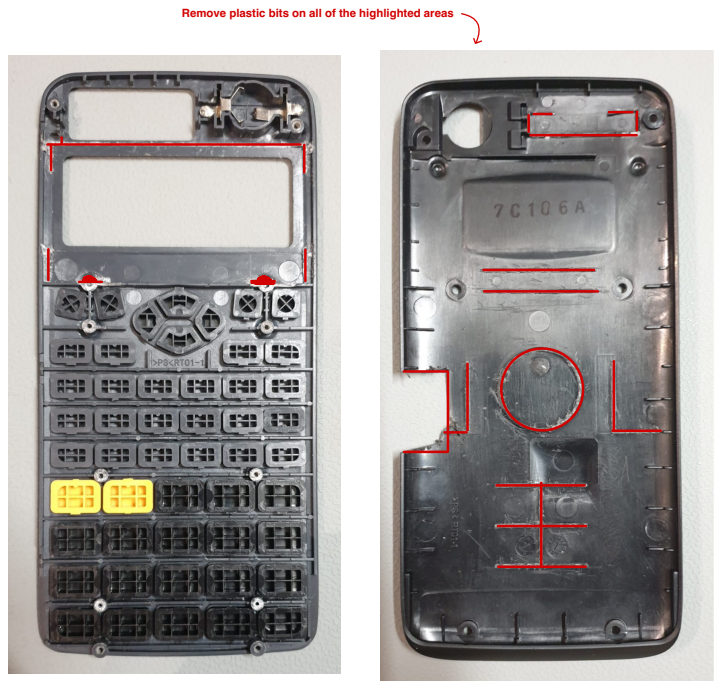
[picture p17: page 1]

Remove plastic bits on all of the highlighted areas

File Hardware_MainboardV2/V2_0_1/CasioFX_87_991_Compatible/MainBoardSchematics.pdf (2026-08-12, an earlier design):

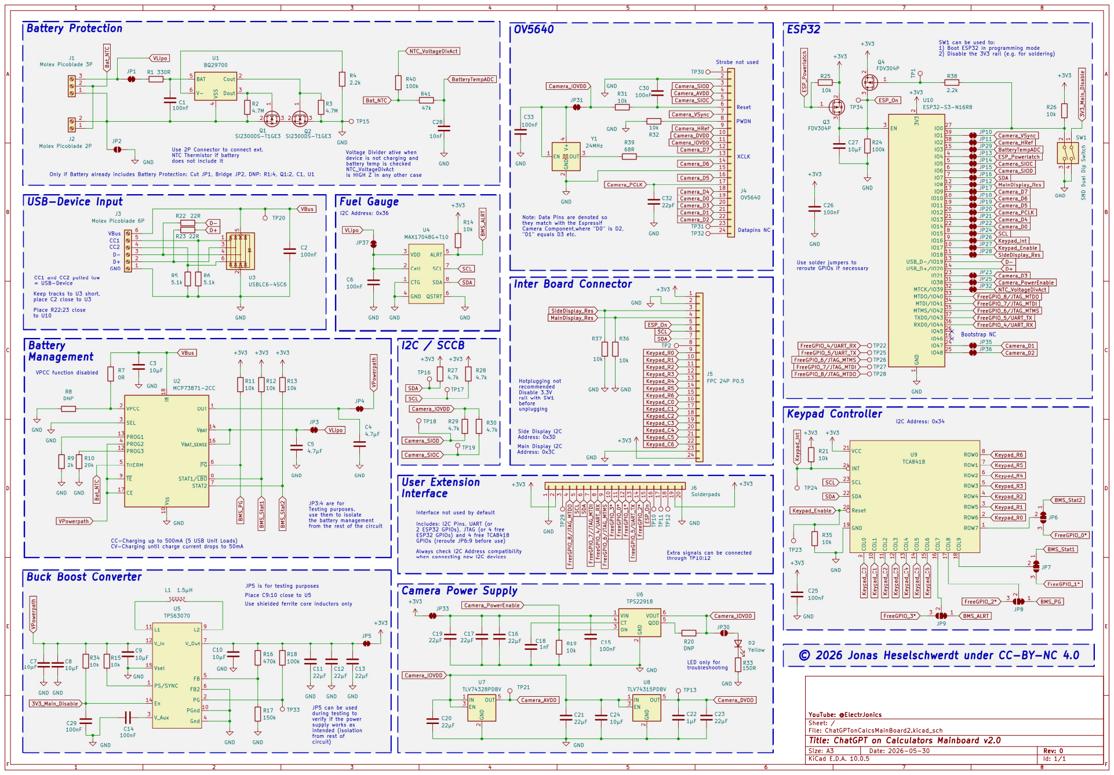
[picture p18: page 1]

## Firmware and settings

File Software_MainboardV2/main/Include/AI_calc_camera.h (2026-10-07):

/*

ChatGPT Hardware Hack for calculators: Software V2

© 2026 Jonas Heselschwerdt
Licensed under GPLv3 

camera.h: Camera settings (using esp_camera component)

*/

// Include

#include "esp_err.h"






// Camera Pins

#define CAM_PIN_PWDN -1         // not used -> hardwired LOW
#define CAM_PIN_N_RESET -1      // not used -> hardwired HIGH
#define CAM_PIN_XCLK -1         // supplied through Y1 on board
#define CAM_PIN_SIOD 6
#define CAM_PIN_SIOC 5

#define CAM_PIN_D7 9
#define CAM_PIN_D6 10
#define CAM_PIN_D5 11
#define CAM_PIN_D4 13
#define CAM_PIN_D3 21
#define CAM_PIN_D2 48
#define CAM_PIN_D1 47
#define CAM_PIN_D0 14
#define CAM_PIN_VSYNC 1
#define CAM_PIN_HREF 2
#define CAM_PIN_PCLK 12





// Needed in esp_camera component

#ifndef portTICK_RATE_MS
#define portTICK_RATE_MS portTICK_PERIOD_MS
#endif




// External XCLK source (Y1)

#define XCLK_EXT_FREQ_MHZ 24





// Framesize codes for camera_set_framesize()
// Indices of the static framesizes-array, get saved as uint8_ts in NVS

#define VGA_640_480_PX 0
#define XGA_1024_768_PX 1
#define UXGA_1600_1200_PX 2
#define QSXGA_2560_1920_PX 3






// Default camera settings

#define DEFAULT_FRAMESIZE_CODE VGA_640_480_PX
#define DEFAULT_JPEG_QUALITY 12




// Camera settings restrictions

#define CAMERA_MAX_JPG_QLTY 64



// Flash memory restrictions

#define PICTURES_MAX_TOTAL_SIZE (3*1024*1024)
#define MAX_SAVED_PICTURES 4

/*
Important: Be very careful about changing PICTURES_MAX_TOTAL_SIZE
Do not set higher than 4 MiB
(only use 8MiB PSRAM models for this project)
*/

#if PICTURES_MAX_TOTAL_SIZE > (4*1024*1024)
#error "Camera directory should not be that large"
#endif







// Exported functions

void camera_init(void);

esp_err_t camera_take_picture(void);
esp_err_t delete_camera_directory(void);

void camera_set_jpeg_quality(uint8_t jpeg_quality);
uint8_t camera_get_jpg_quality(void);
void camera_set_framesize(uint8_t framesize_code);

esp_err_t get_saved_pictures_paths(size_t* directory_size, uint8_t* file_cnt, char (*pic_paths)[64]);
esp_err_t get_saved_pics(uint8_t* pic_cnt);

void camera_start_debug_http_server(void);      // Only for debugging
void camera_end_debug_http_server(void);        // Only for debugging

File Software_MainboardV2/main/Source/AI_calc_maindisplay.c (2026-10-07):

/*

ChatGPT Hardware Hack for calculators: Software V2

© 2026 Jonas Heselschwerdt
Licensed under GPLv3

maindisplay.h: Functions and variables to control the DOGM204 text LCD via I2C

*/

// #region Includes

/*
#########################################################################################
##                                                                                     ##
##  Includes                                                                           ##
##                                                                                     ##
#########################################################################################
*/

#include "esp_err.h"
#include "esp_log.h"
#include "driver/i2c_master.h"
#include "driver/gpio.h"
#include "freertos/FreeRTOS.h"
#include "freertos/task.h"
#include "string.h"

#include "AI_calc_main.h"
#include "AI_calc_device.h"
#include "AI_calc_UI.h"
#include "AI_calc_maindisplay.h"

// #endregion

// #region Static variables

/*
#########################################################################################
##                                                                                     ##
##  Static variables                                                                   ##
##                                                                                     ##
#########################################################################################
*/

static i2c_master_dev_handle_t dogm204_dev = NULL;

static uint8_t MainDisplay_LUT[256];
static char MainDisplayReverseLUT[256];

static EventGroupHandle_t loading_events;
static TaskHandle_t loading_task_handle;

static uint16_t loading_screen_advance_interval_ms;
static char loading_text[MAIN_DISPLAY_COLUMNS+1];
static char loading_progress_bar[MAIN_DISPLAY_COLUMNS+1] = {
    // Gets rotated around in loading screen
    ' ',
    DOGM204_HALFHOLLOWBLOCK,
    DOGM204_FULLBLOCK,
    DOGM204_FULLBLOCK,
    DOGM204_HALFHOLLOWBLOCK,
    DOGM204_HOLLOWBLOCK,
    DOGM204_HOLLOWBLOCK,
    DOGM204_HOLLOWBLOCK,
    DOGM204_HOLLOWBLOCK,
    DOGM204_HOLLOWBLOCK,
    DOGM204_HOLLOWBLOCK,
    DOGM204_HOLLOWBLOCK,
    DOGM204_HOLLOWBLOCK,
    DOGM204_HOLLOWBLOCK,
    DOGM204_HOLLOWBLOCK,
    DOGM204_HOLLOWBLOCK,
    DOGM204_HOLLOWBLOCK,
    DOGM204_HOLLOWBLOCK,
    DOGM204_HOLLOWBLOCK,
    ' ',
    '\0'
};
static char* loading_screen[MAIN_DISPLAY_ROWS] = {
    EMPTY_LINE,
    loading_text,
    loading_progress_bar,
    EMPTY_LINE
}; 


static const char animation_divider[] = {
    // Is insterted between transitions in dogm204_print_screen_fancy()
    ' ',
    ' ',
    ' ',
    DOGM204_HALFHOLLOWBLOCK,
    DOGM204_FULLBLOCK,
    DOGM204_HALFHOLLOWBLOCK,
    ' ',
    ' ',
    ' ',
    '\0'
};

// #endregion

// #region Extern variables

/*
#########################################################################################
##                                                                                     ##
##  Extern variables                                                                   ##
##                                                                                     ##
#########################################################################################
*/

char empty_line[MAIN_DISPLAY_COLUMNS+1] = "                    ";
char style_line_equal_sign[MAIN_DISPLAY_COLUMNS+1] = "====================";

// #endregion


// #region Static function declarations

/*
#########################################################################################
##                                                                                     ##
##  Static function declarations                                                       ##
##                                                                                     ##
#########################################################################################
*/

// Base functions
static void dogm204_write_cmd(uint8_t cmd);
static void dogm204_write_data(uint8_t data);
static void dogm204_read_data(uint8_t* data);
static uint8_t dogm204_screen_text_valid(char** screen_text);
// Init functions
static void initialize_MainDisplayLUT(void);
static void initialize_MainDisplayReverseLUT(void);
static void dogm204_define_custom_symbols(void);
static void dogm204_create_symbol(uint8_t* symbol_data, uint8_t cgram_addr);
// Display read functions
static void dogm204_read_screen(uint8_t* displaydata);
static void dogm204_displaydata_to_string(char** screen_text, uint8_t* displaydata);
// Loading screen
static void dogm204_loading_screen_task_init(void);
static void dogm204_advance_loading_screen(void);
static void dogm204_loading_screen_task(void* arg);

// #endregion

// #region Static functions

/*
#########################################################################################
##                                                                                     ##
##   Static functions                                                                  ##
##                                                                                     ##
#########################################################################################
*/

static void dogm204_write_cmd(uint8_t cmd){

    uint8_t buf[2] = {
        0x00,     
        cmd
    };
    ESP_ERROR_CHECK(i2c_master_transmit(dogm204_dev, buf, sizeof(buf), -1));
    // Give a little bit of time for command processing
    vTaskDelay(pdMS_TO_TICKS(5));
}

static void dogm204_write_data(uint8_t data){

    uint8_t buf[2] = {
        0x40,
        data
    };
    ESP_ERROR_CHECK(i2c_master_transmit(dogm204_dev, buf, sizeof(buf), -1));
}

static void dogm204_read_data(uint8_t* data){ 

    uint8_t command = 0x40;
    ESP_ERROR_CHECK(i2c_master_transmit(dogm204_dev, &command, 1, -1));
    uint8_t data_buf[3];
    ESP_ERROR_CHECK(i2c_master_receive(dogm204_dev, data_buf, 3, -1));
    *data = data_buf[2];
}

static uint8_t dogm204_screen_text_valid(char** screen_text){

    // Check if strings are valid (same length as MAIN_DISPLAY_COLUMNS)
    char error_info[MAIN_DISPLAY_COLUMNS+1];
    for (uint8_t i=0; i<MAIN_DISPLAY_ROWS; i++){
        if (strlen(screen_text[i]) < MAIN_DISPLAY_COLUMNS){
            snprintf(error_info,sizeof(error_info),"LINE%3u %3uTOOSHORT ",i,(uint8_t)(MAIN_DISPLAY_COLUMNS-strlen(screen_text[i])));
            dogm204_print_error_screen(error_info,ERROR_SOURCE_MAIN_DISPLAY);
            return 0;
        }
        if (strlen(screen_text[i]) > MAIN_DISPLAY_COLUMNS){
            snprintf(error_info,sizeof(error_info),"LINE%3u %3uTOOLONG  ",i,(uint8_t)(strlen(screen_text[i])));
            dogm204_print_error_screen(error_info,ERROR_SOURCE_MAIN_DISPLAY);
            return 0;
        }
    }
    return 1;
}

static void dogm204_read_screen(uint8_t* displaydata){

    dogm204_write_cmd(DOGM204_RETURN_HOME);
    dogm204_set_cursor_position(20,4);
    for (uint8_t i=1; i<=MAIN_DISPLAY_ROWS; i++){
        for (uint8_t j=1; j<=MAIN_DISPLAY_COLUMNS; j++){
            dogm204_set_cursor_position(j,i);
            dogm204_read_data(&displaydata[((i-1)*MAIN_DISPLAY_COLUMNS)+(j-1)]);
        }
    }
    /*
    For some reason, the cursor seems to get shifted before each DDRAM read, 
    because of this quirk of the SSD1803A the displaydata array needs to be 'rotated' by one
    */
    uint8_t temp_buf = displaydata[(MAIN_DISPLAY_CHARACTERS)-1];
    for (uint8_t i=((MAIN_DISPLAY_CHARACTERS)-1); i>0; i--){
        displaydata[i] = displaydata[i-1];
    }
    displaydata[0]=temp_buf;
}

static void initialize_MainDisplayLUT(void){

    // Character to DDRAM code LUT
    for (uint16_t i=0; i<256; i++){
        MainDisplay_LUT[i] = 0x20;
    }
    // Big letters
    MainDisplay_LUT['A'] = 0x41;
    MainDisplay_LUT['B'] = 0x42;
    MainDisplay_LUT['C'] = 0x43;
    MainDisplay_LUT['D'] = 0x44;
    MainDisplay_LUT['E'] = 0x45;
    MainDisplay_LUT['F'] = 0x46;
    MainDisplay_LUT['G'] = 0x47;
    MainDisplay_LUT['H'] = 0x48;
    MainDisplay_LUT['I'] = 0x49;
    MainDisplay_LUT['J'] = 0x4A;
    MainDisplay_LUT['K'] = 0x4B;
    MainDisplay_LUT['L'] = 0x4C;
    MainDisplay_LUT['M'] = 0x4D;
    MainDisplay_LUT['N'] = 0x4E;
    MainDisplay_LUT['O'] = 0x4F;
    MainDisplay_LUT['P'] = 0x50;
    MainDisplay_LUT['Q'] = 0x51;
    MainDisplay_LUT['R'] = 0x52;
    MainDisplay_LUT['S'] = 0x53;
    MainDisplay_LUT['T'] = 0x54;
    MainDisplay_LUT['U'] = 0x55;
    MainDisplay_LUT['V'] = 0x56;
    MainDisplay_LUT['W'] = 0x57;
    MainDisplay_LUT['X'] = 0x58;
    MainDisplay_LUT['Y'] = 0x59;
    MainDisplay_LUT['Z'] = 0x5A;
    // Small letters
    MainDisplay_LUT['a'] = 0x61;
    MainDisplay_LUT['b'] = 0x62;
    MainDisplay_LUT['c'] = 0x63;
    MainDisplay_LUT['d'] = 0x64;
    MainDisplay_LUT['e'] = 0x65;
    MainDisplay_LUT['f'] = 0x66;
    MainDisplay_LUT['g'] = 0x67;
    MainDisplay_LUT['h'] = 0x68;
    MainDisplay_LUT['i'] = 0x69;
    MainDisplay_LUT['j'] = 0x6A;
    MainDisplay_LUT['k'] = 0x6B;
    MainDisplay_LUT['l'] = 0x6C;
    MainDisplay_LUT['m'] = 0x6D;
    MainDisplay_LUT['n'] = 0x6E;
    MainDisplay_LUT['o'] = 0x6F;
    MainDisplay_LUT['p'] = 0x70;
    MainDisplay_LUT['q'] = 0x71;
    MainDisplay_LUT['r'] = 0x72;
    MainDisplay_LUT['s'] = 0x73;
    MainDisplay_LUT['t'] = 0x74;
    MainDisplay_LUT['u'] = 0x75;
    MainDisplay_LUT['v'] = 0x76;
    MainDisplay_LUT['w'] = 0x77;
    MainDisplay_LUT['x'] = 0x78;
    MainDisplay_LUT['y'] = 0x79;
    MainDisplay_LUT['z'] = 0x7A;
    // Other ASCII Symbols
    MainDisplay_LUT['!'] = 0x21;
    MainDisplay_LUT['"'] = 0x22;
    MainDisplay_LUT['#'] = 0x23;
    MainDisplay_LUT['$'] = 0xA2;
    MainDisplay_LUT['%'] = 0x25;
    MainDisplay_LUT['&'] = 0x26;
    MainDisplay_LUT['\''] = 0x27;
    MainDisplay_LUT['('] = 0x28;
    MainDisplay_LUT[')'] = 0x29;
    MainDisplay_LUT['*'] = 0x2A;
    MainDisplay_LUT['+'] = 0x2B;
    MainDisplay_LUT[','] = 0x2C;
    MainDisplay_LUT['-'] = 0x2D;
    MainDisplay_LUT['.'] = 0x2E;
    MainDisplay_LUT['/'] = 0x2F;
    MainDisplay_LUT[':'] = 0x3A;
    MainDisplay_LUT[';'] = 0x3B;
    MainDisplay_LUT['<'] = 0x3C;
    MainDisplay_LUT['='] = 0x3D;
    MainDisplay_LUT['>'] = 0x3E;
    MainDisplay_LUT['?'] = 0x3F;
    MainDisplay_LUT['@'] = 0xA0;
    MainDisplay_LUT['['] = 0xFA;
    MainDisplay_LUT['\\'] = 0xFB;
    MainDisplay_LUT[']'] = 0xFC;
    MainDisplay_LUT['^'] = 0x1D;
    MainDisplay_LUT['_'] = 0xC4;
    MainDisplay_LUT['{'] = 0xFD;
    MainDisplay_LUT['}'] = 0xFF;
    MainDisplay_LUT['~'] = 0xDE;
    MainDisplay_LUT[' '] = 0x20;
    // Numbers
    MainDisplay_LUT['0'] = 0x30;
    MainDisplay_LUT['1'] = 0x31;
    MainDisplay_LUT['2'] = 0x32;
    MainDisplay_LUT['3'] = 0x33;
    MainDisplay_LUT['4'] = 0x34;
    MainDisplay_LUT['5'] = 0x35;
    MainDisplay_LUT['6'] = 0x36;
    MainDisplay_LUT['7'] = 0x37;
    MainDisplay_LUT['8'] = 0x38;
    MainDisplay_LUT['9'] = 0x39;
    // Other non-ASCII symbols
    MainDisplay_LUT[DOGM204_FULLBLOCK] = 0x1F;
    MainDisplay_LUT[DOGM204_DEGREE_SIGN] = 0x80;        // using ^0 as 'degree' sign
    MainDisplay_LUT[DOGM204_DELTA_SIGN] = 0xB0;
    MainDisplay_LUT[DOGM204_MENU_POINTER_SIGN] = 0x10;
    MainDisplay_LUT[DOGM204_BALL_SIGN] = 0xBB;
}

static void initialize_MainDisplayReverseLUT(void){

    // DDRAM code to char LUT, useful with dogm04_read_screen
    // Gets synched with MainDisplayLUT automatically
    for (uint16_t i=0; i<256; i++){
        // default value
        MainDisplayReverseLUT[i]=' ';
    }
    for (uint16_t i=0; i<256; i++){
        MainDisplayReverseLUT[MainDisplay_LUT[i]]=(char)i;
    }
}

static void dogm204_displaydata_to_string(char** screen_text, uint8_t* displaydata){

    for (uint8_t i=0; i<MAIN_DISPLAY_ROWS; i++){
        for (uint8_t j=0; j<MAIN_DISPLAY_COLUMNS; j++){
            screen_text[i][j]=MainDisplayReverseLUT[displaydata[(i*MAIN_DISPLAY_COLUMNS)+j]];
        }
        screen_text[i][MAIN_DISPLAY_COLUMNS]='\0';
    }
}

static void dogm204_create_symbol(uint8_t* symbol_data, uint8_t cgram_addr){

    if (cgram_addr > 7){
        // Invalid CGRAM-ADDR
        dogm204_print_error_screen("INVALID CGRAM       ",ERROR_SOURCE_MAIN_DISPLAY);
        vTaskDelay(pdMS_TO_TICKS(1000));
        return;
    }
    dogm204_write_cmd(DOGM204_FUNCTION_SET);
    for (uint8_t i=0; i<MAIN_DISPLAY_CHARACTERSIZE_Y; i++){
        dogm204_write_cmd(DOGM204_SET_CGRAM_ADDR|(cgram_addr<<3)|i);
        dogm204_write_data(symbol_data[i]);
    }

}

static void dogm204_define_custom_symbols(void){

    // Create custom symbol (MAIN_DISPLAY_CHARACTERSIZE_X * MAIN_DISPLAY_CHARACTERSIZE_Y) 
    // for display progress bar
    uint8_t hollowblock_sign[8] = {
        // Bits 5-7 are irrelevant              Looks like:
        0b00011111,                     //      0   0   0   0   0    
        0b00010001,                     //      0               0
        0b00010001,                     //      0               0
        0b00010001,                     //      0               0
        0b00010001,                     //      0               0
        0b00010001,                     //      0               0
        0b00010001,                     //      0               0
        0b00011111                      //      0   0   0   0   0
    };
    MainDisplay_LUT[DOGM204_HOLLOWBLOCK] = 0x00;
    dogm204_create_symbol(hollowblock_sign,MainDisplay_LUT[DOGM204_HOLLOWBLOCK]);
    uint8_t halfhollowblock_sign[8] = {
        0b00011111,                     //      0   0   0   0   0
        0b00010101,                     //      0       0       0
        0b00011011,                     //      0   0       0   0
        0b00010101,                     //      0       0       0
        0b00011011,                     //      0   0       0   0
        0b00010101,                     //      0       0       0
        0b00011011,                     //      0   0       0   0
        0b00011111                      //      0   0   0   0   0
    };
    MainDisplay_LUT[DOGM204_HALFHOLLOWBLOCK] = 0x01;
    dogm204_create_symbol(halfhollowblock_sign,MainDisplay_LUT[DOGM204_HALFHOLLOWBLOCK]);
    // for battery info screen
    uint8_t battery_sign[8] = {
        0b00001110,                     //          0   0   0    
        0b00011011,                     //      0   0       0   0
        0b00010011,                     //      0           0   0
        0b00010101,                     //      0       0       0
        0b00011111,                     //      0   0   0   0   0
        0b00010101,                     //      0       0       0
        0b00011001,                     //      0   0           0
        0b00011111                      //      0   0   0   0   0
    };
    MainDisplay_LUT[DOGM204_BATTERY_SIGN] = 0x02;
    dogm204_create_symbol(battery_sign,MainDisplay_LUT[DOGM204_BATTERY_SIGN]);
}

static void dogm204_loading_screen_task_init(void){

    loading_events = xEventGroupCreate();
    xTaskCreate(dogm204_loading_screen_task,"LoadingScreen",2048,NULL,2,&loading_task_handle);
}

static void dogm204_loading_screen_task(void* arg){

    // Shows a loading screen while not blocking app_main
    while(1){
        xEventGroupWaitBits(loading_events,LOADING_ACTIVE_BIT,pdFALSE,pdTRUE,portMAX_DELAY);
        dogm204_advance_loading_screen();
        vTaskDelay(pdMS_TO_TICKS(loading_screen_advance_interval_ms));
    }
}

static void dogm204_advance_loading_screen(void){

    uint8_t progress_bar_DDRAM_codes[MAIN_DISPLAY_COLUMNS-2];
    // Read current state of progress bar
    for (uint8_t i=2; i<MAIN_DISPLAY_COLUMNS; i++){
        // Set cursor x one cursor position in front of progressbar,
        // see dogm204_read_screen above for the reason
        dogm204_set_cursor_position(i-1,3);
        dogm204_read_data(&progress_bar_DDRAM_codes[i-2]);
    }
    // Rotate values of progress bar
    uint8_t temp_buf = progress_bar_DDRAM_codes[MAIN_DISPLAY_COLUMNS-3];
    for (uint8_t i=(MAIN_DISPLAY_COLUMNS - 3); i >= 1; i--) {
        progress_bar_DDRAM_codes[i] = progress_bar_DDRAM_codes[i - 1];
    }
    progress_bar_DDRAM_codes[0]=temp_buf;
    // Clear progress bar and update it
    dogm204_set_cursor_position(2,3);
    for (uint8_t i=0; i<(MAIN_DISPLAY_COLUMNS-2); i++){
        dogm204_write_data(MainDisplay_LUT[' ']);
    }
    dogm204_set_cursor_position(2,3);
    for (uint8_t i=0; i<(MAIN_DISPLAY_COLUMNS-2); i++){
        dogm204_write_data(progress_bar_DDRAM_codes[i]);
    }
}

// #endregion

// #region Extern Functions

/*
#########################################################################################
##                                                                                     ##
##   Extern functions                                                                  ##
##                                                                                     ##
#########################################################################################
*/

void dogm204_init(void){

    i2c_device_config_t dogm204_config = {
        .device_address = DOGM204_I2C_ADDR,
        .scl_speed_hz = I2C_FREQ
    };
    ESP_ERROR_CHECK(i2c_master_bus_add_device(i2c_bus,&dogm204_config,&dogm204_dev));

    gpio_set_level(MAIN_DISPLAY_N_RESET,1);
    vTaskDelay(pdMS_TO_TICKS(100));

    // Init-Sequence start
    dogm204_write_cmd(DOGM204_FUNCTION_SET|DOGM204_RE_BIT);
    dogm204_write_cmd(DOGM204_EXT_FUNCTION_SET|DOGM204_FANCY_CURSOR_BIT);
    dogm204_write_cmd(DOGM204_ENTRY_MODE_SET|DOGM204_TOP_VIEW_BIT);
    dogm204_write_cmd(DOGM204_BIAS_SET);
    dogm204_write_cmd(DOGM204_FUNCTION_SET|DOGM204_IS_BIT);
    dogm204_write_cmd(DOGM204_INTERNAL_OSC);
    dogm204_write_cmd(DOGM204_FOLLOWER_CONTROL);
    dogm204_set_contrast(device.main_display_contrast);
    dogm204_write_cmd(DOGM204_FUNCTION_SET);
    // clear display befor turning display on, so no 'Junk data' shows up
    dogm204_clear_screen();
    dogm204_display_control(DOGM204_CURSOR_OFF_BIT|DOGM204_CURSOR_NO_BLINK_BIT|DOGM204_DISPLAY_ON_BIT);
    // Default cursor shift direction -> right
    dogm204_set_cursor_shift_dir(DOGM204_CURSOR_RIGHT_SHIFT);
    dogm204_write_cmd(DOGM204_FUNCTION_SET|DOGM204_RE_BIT);
    // Dual byte command start
    dogm204_write_cmd(DOGM204_ROM_SELECT);
    dogm204_write_data(DOGM204_ROM_SETTINGS|DOGM204_ROM_A_BIT);
    // Dual byte command end
    dogm204_write_cmd(DOGM204_FUNCTION_SET);
    // Init-Sequence end
    initialize_MainDisplayLUT();
    dogm204_define_custom_symbols();
    initialize_MainDisplayReverseLUT();

    dogm204_loading_screen_task_init();
}







void dogm204_set_contrast(uint8_t contrast){

    // Contrast can be set from 0-63
    // IS Bit = 1, RE Bit = 0
    if (contrast > 0x3F){
        // contrast-value to high, set to max
        dogm204_write_cmd(DOGM204_FUNCTION_SET|DOGM204_IS_BIT);
        dogm204_write_cmd(DOGM204_POWER_CTRL|0x03);
        dogm204_write_cmd(DOGM204_CONTRAST_SET|0x0F);
    }
    else{
        dogm204_write_cmd(DOGM204_FUNCTION_SET|DOGM204_IS_BIT);
        dogm204_write_cmd(DOGM204_POWER_CTRL|(contrast >> 4));
        dogm204_write_cmd(DOGM204_CONTRAST_SET|(contrast & 0x0F));
    }
    // IS and RE Bits back to default
    dogm204_write_cmd(DOGM204_FUNCTION_SET); 
}

void dogm204_display_control(uint8_t display_settings){

    // IS Bit = 0, RE Bit = 0
    dogm204_write_cmd(DOGM204_FUNCTION_SET);
    dogm204_write_cmd(DOGM204_DISPLAY_ONOFF_CTRL|display_settings);
}

void dogm204_set_cursor_shift_dir(uint8_t dir){

    // IS Bit = 0, RE Bit = 0
    dogm204_write_cmd(DOGM204_FUNCTION_SET);
    dogm204_write_cmd(DOGM204_ENTRY_MODE_SET|dir);
    
}

void dogm204_set_cursor_position(uint8_t x, uint8_t y){

    /*
    Cursor coordinates are 1-based!
    x = 1 & y = 1 -> Top left corner of display
    x = MAIN_DISPLAY_COLUMNS & y = MAIN_DISPLAY_ROWS -> Bottom right corner of display
    */
    uint8_t display_ram_coords = 0x00;
    display_ram_coords = display_ram_coords + (0x20 * (y-1));
    display_ram_coords = display_ram_coords + (0x01 * (x-1));
    dogm204_write_cmd(DOGM204_SET_DDRAM_ADDR + display_ram_coords);
}









void dogm204_clear_screen(void){

    dogm204_write_cmd(DOGM204_CLEAR_SCREEN);
}

void dogm204_print_error_screen(char* error_message_string, char* error_source_string){

    if (xEventGroupGetBits(loading_events) & LOADING_ACTIVE_BIT){
        // Has higher priority than loading screen
        dogm204_end_loading_screen();
    }
    dogm204_write_cmd(DOGM204_FUNCTION_SET);
    dogm204_write_cmd(DOGM204_CLEAR_SCREEN);
    dogm204_set_cursor_shift_dir(DOGM204_CURSOR_RIGHT_SHIFT);
    for (uint8_t i=0; i<MAIN_DISPLAY_COLUMNS; i++){
        dogm204_write_data(MainDisplay_LUT[(uint8_t)error_source_string[i]]);
    }
    for (uint8_t i=0; i<MAIN_DISPLAY_COLUMNS; i++){
        dogm204_write_data(MainDisplay_LUT[(uint8_t) error_message_string[i]]);
    }
}

void dogm204_print_screen(char** screen_text){

    if (xEventGroupGetBits(loading_events) & LOADING_ACTIVE_BIT){
        dogm204_end_loading_screen();
        dogm204_print_error_screen("INTERRUPTING LOADING",WARNING_SOURCE_MAIN_DISPLAY);
        vTaskDelay(pdMS_TO_TICKS(1000));
    }
    dogm204_write_cmd(DOGM204_FUNCTION_SET);
    dogm204_clear_screen();
    if (!dogm204_screen_text_valid(screen_text)){
        return;
    }
    for (uint8_t i=0; i<MAIN_DISPLAY_ROWS; i++){
        for (uint8_t j=0; j<MAIN_DISPLAY_COLUMNS; j++){
            dogm204_write_data(MainDisplay_LUT[(uint8_t)screen_text[i][j]]);
        }
    }
}
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

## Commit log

2026-01-12 Added documentation and kicad files, changed comments to english
2026-01-24 Added 3d-prints, added BOM
    [PCB_case_connector_washer.3mf, Plastic_bracket.3mf, Solar_panel_holder.3mf]
2026-02-19 Prototype v.1.1.0
    [partitions.csv]
2026-07-24 Hardware v2.0.0
    [BOM.xlsx, BackcaseFX991_FX87.3mf, BatteryTrayFX991_FX87.step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]
2026-08-04 Fully implemented and tested new main display drivers
2026-08-12 Added battery management (not fully tested)
2026-08-12 Hardware v2.0.1 (small fixes)
    [BOM.xlsx]
2026-09-26 First (somewhat) stable V2 with equation rendering
    [BOM.xlsx, BackcaseFX991_FX87.3mf, BackcaseFX991_FX87.step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]
2026-09-26 V2 with equation rendering
    [BOM.xlsx, BackcaseFX991_FX87.3mf, BackcaseFX991_FX87.step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]
2026-09-26 Hwv2.0.2 (improved board design)
    [BOM.xlsx]
2026-10-07 HWv2.0.3 + Changed Licence
    [BOM.xlsx, Washer_Thingy_for_UI_Board.3mf]
2026-10-24 SWv2.0.1 + PCBA files for mainboard
